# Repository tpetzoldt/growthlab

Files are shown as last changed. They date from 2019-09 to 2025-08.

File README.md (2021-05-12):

# growthlab

## Reale und virtuelle Wachstumsexperimente für Schule und Studium

## Real and virtual growth experiments for highschool and university students

Note to English speaking people: This repository is partly in German to support use by private persons and in schools in Germany.

Wachstums- und Verlustprozesse spielen in den ökologischen Wissenschaften eine entscheidende Rolle, nicht nur bei Symbolarten wie dem amerikanischen Bison [1], sondern auch bei Bakterien, beim Phytoplankton oder bei Fischen. Biologische Systeme besitzen eine vielfältige Dynamik und sind häufig komplex und rückgekoppelt, Simulationen und Experimente tragen zum Verständnis bei.

Das Repository ist eine lose Sammlung von Codes und Beschreibungen realer und virtueller Experimente zum Thema Wachstum für Schule und Studium. Beispiele sind web-basierte Simulationen (Laborversuch, Kläranlage, Flachsee) auf dem Computer oder Tablet, zum anderen um kleine Laborexperimente, die die reale mit der virtuellen Welt verbinden. Ziel ist Anschaulichkeit und ein einfacher Einstieg, die Luft nach oben ist offen.

Mit Hilfe von Flaschenversuchen wird das Populationswachstum einer Mikroalgenkultur beobachtet, z.B. von Scenedesmus. Die Messeinrichtung besteht aus kostengünstigen Bauteilen und eignet sich für Praktikumsversuche, Schulexperimente und Hobbyforscher. Das Grundprinzip ist ein Gestell mit roter Laserdiode, einem Fotowiderstand und einem Temperatursensor sowie einer LED-Beleuchtung und einem selbstgebauten Magnetrührer. Für die Stromversorgung genügt ein 5V-USB-Netzteil, z.B. von einem Handy. Die Messung kann direkt in der Flasche erfolgen, ohne den Versuch zu unterbrechen.

Die optische Dichte der Planktonkultur wird im einfachsten Fall manuell mit einem Voltmeter gemessen. In der vollen Ausbaustufe erfolgt die Messung mit einem WLAN-fähigen Mikrocontroller (Espressif ESP32), der gleichzeitig Beleuchtung und Rührer steuert, die Temperatur überwacht und die Daten an einen Server (z.B. einen Raspberry Pi "Bastelcomputer") oder einen Cloudservice überträgt.

Je nach Ausbaustufe ist das Experiment sehr einfach und erfordert weder Programmierung noch den Umgang mit einem Lötkolben. Im größeren Maßstab kann es ein fächerübergreifendes „Maker-Projekt“ (siehe [1,2]) für Teams werden: mechanischer Aufbau der Versuchsanordnung, Aufbau einer Schaltung, Mikrocontroller-Programmierung, Datenübertragung („Internet of Things“), Finden und Kennenlernen geeigneter Organismen, mikroskopische oder fotometrische Kalibrierung, Herstellen von Kulturmedien, Datenbankstruktur, statistische Datenanalyse und mechanistische Modellierung.

Der Versuchsaufbau wurde im Rahmen von Schülerpraktika (Gymnasium 11. und 12. Klasse) entwickelt. Die gewonnen Daten werden in Kursen zu ökologischer Statistik und Modellierung verwendet.

Ausführliche Dokumentation auf https://tpetzoldt.github.io/growthlab

### Grundideen

* [Ein Arduino steuert das Licht](https://tpetzoldt.github.io/growthlab/doc/blink.html)
* [Versuchsaufbau: Steuerung, Sensoren, Daten](https://tpetzoldt.github.io/growthlab/doc/versuchsaufbau.html)

### Schülerprojekte

* [Jugend Forscht-Projekt 2019/2020 -- Wachstumsversuche:](https://tpetzoldt.github.io/growthlab/doc/petzoldt_belger_2019.pdf) Experimente zur Messung des Wachstums einer Phytoplanktonpopulation
* [Jugend Forscht-Projekt 2020/2021 -- Algenlogger:](https://tpetzoldt.github.io/growthlab/doc/algenlogger.html) Versuchsoptimierung, Kalibrierung und Langzeitexperimente

### Quelltexte, Software und Bilder

* [Software-Repository](https://github.com/tpetzoldt/growthlab/)

### Literatur

[1] Snider, S. B. & Brimlow, J. N. (2013) An Introduction to Population Growth. Nature Education Knowledge 4(4):3 https://www.nature.com/scitable/knowledge/library/an-introduction-to-population-growth-84225544/ abgerufen am 2020-02-12

[2] Obama, B. (2014) Nation of Makers. https://obamawhitehouse.archives.gov/nation-of-makers abgerufen am 2019-05-28

[3] Wikipedia (2019) Makerbewegung. https://de.wikipedia.org/wiki/Maker abgerufen am 2019-05-28

### Nutzungsbedingungen

Falls nicht anders angegeben sind **Codes**, Texte und Abbildungen unter der GNU General Public License lizenziert, und zwar wahlweise unter der [GPL 2.0](http://www.gnu.org/licenses/gpl-2.0) oder der [GPL 3.0](http://www.gnu.org/licenses/gpl-3.0).

Die **Texte** und **Abbildungen** können außerdem (und falls nicht anders angegeben) auch gemäß der Creative Commons-Lizenz [CC BY 4.0](https://creativecommons.org/licenses/by/4.0/) verwendet werden. Falls im Einzelfall eine andere Lizenz gelten sollte, ist dies im jeweiligen Unterverzeichnis bzw. direkt im Dokument vermerkt.

Die Doppellizenzierung (GPL bzw. CC BY) berücksichtigt unterschiedliche Gepflogenheiten bei freier Software (Code) und freier Dokumentation (Texte, Abbildungen). In beiden Fällen, können Materialien im Rahmen von schulischen, akademischen oder privaten Projekten frei verwendet werden. Eine kommerzielle Nutzung ist ebenfalls möglich.

Namensnennung: Beide Lizenzen (GPL und CC BY) erfordern eine Namensnennung. Bitte nennen Sie die Institution und die im Dokument genannten Autor:innen und verlinken Sie mit der Webseite. Bei Rückfragen kontaktieren Sie bitte den [Maintainer](https://github.com/tpetzoldt).

Beispiel: Name der Autor:in (2019) Titel des Teildokuments. **growthlab**: Reale und virtuelle Wachstumsexperimente für Schule und Studium. TU Dresden, Institut für Hydrobiologie, https://github.com/tpetzoldt/growthlab 

----

<a href="https://open-educational-resources.de/">
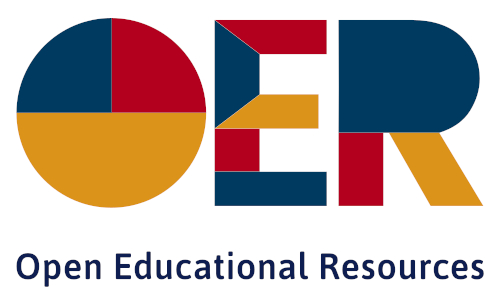
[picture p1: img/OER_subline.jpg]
OER Logo

</a>
<a href="https://creativecommons.org/licenses/by/4.0/">
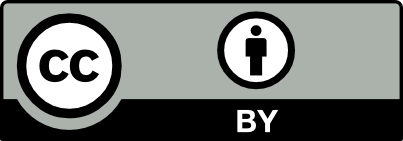
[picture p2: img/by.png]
CC BY Logo

</a>
<a href="http://www.gnu.org/licenses/gpl-3.0">
GPL v3 Logo
</a>

[tpetzoldt](https://github.com/tpetzoldt) 2021-05-12

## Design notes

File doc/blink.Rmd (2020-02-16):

---
title: "Blinkender LED-Streifen"
author: "Thomas Petzoldt"
date: "2019-10-07"
output: 
  html_document:
    numbersections: true
    toc: true
    toc_float:
      collapsed: false
      smooth_scroll: true
    code_folding: hide

---

# Grundidee

Die Grundidee besteht darin, einen LED-Streifen zur Beleuchtung eines 
Wachstumsversuchs zu verwenden. Mit Hilfe eines Microcontrollers sollen unterschiedliche
Hell-Dunkel-Zyklen einstellbar sein, z.B. 12:12, 16:8 oder 2:2 Stunden.

Das Experiment ist als Schüler-, Studien- und Praktikumsexperiment vorgesehen. 
Bei entsprechend höherem Aufwand und Kosten für Mechanik, Optik und Elektronik 
ist eine Weiterentwicklung für Forschungszwecke denkbar, allerdings sind
solche Geräte bereits kommerziell erhältlich.

Im folgenden soll der Versuch, ausgehend von der Grundidee, schrittweise bis zur
Vollautomatisierung und zur Integration in ein Netzwerk (IoT -- Internet of Things)
vorgestellt werden.

Das hier vorgefundene Dokument stellt den jeweiligen Arbeitsstand dar.

# LED-Streifen

LED-Streifen sind in zahlreichen unterschiedlichen Versionen erhältlich, die sich durch Leistung, Lichtfarbe, und Versorgungsspannung unterscheiden. Die benötigte Leistung ist im Regelfall höher, als die vom Arduino oder ESP am digitalen Pin erreichbaren Werte, außerdem beträgt die Versorgungsspannung oft 12 oder 24V und nicht 3.3 oder 5V wie beim Mikrocontroller. Es sind deshalb Bauteile zur Steuerung etwas höherer Leistungen erforderlich.

Die folgende Anleitung beginnt zunächst mit der Steuerung von einfachen LEDs, anschließend wird das Experiment zur Steuerung etwas höherer Leistungen erweitert.

# Experiment 1 

Die einfachste Aufbaustufe zeigt bereits das Grundprinzip.

Als elektronische Bauelemente genügen neben der LED und dem Arduino ein sogenanntes *Breadboard* (Steckbrett),
1 Widerstand, 1 LED und ein paar Steckbrücken oder Basteldraht (0.5mm Durchmesser). Wichtig ist, dass
die LED immer mit einem Vorwiderstand betrieben werden muss, sonst geht sie kaputt.

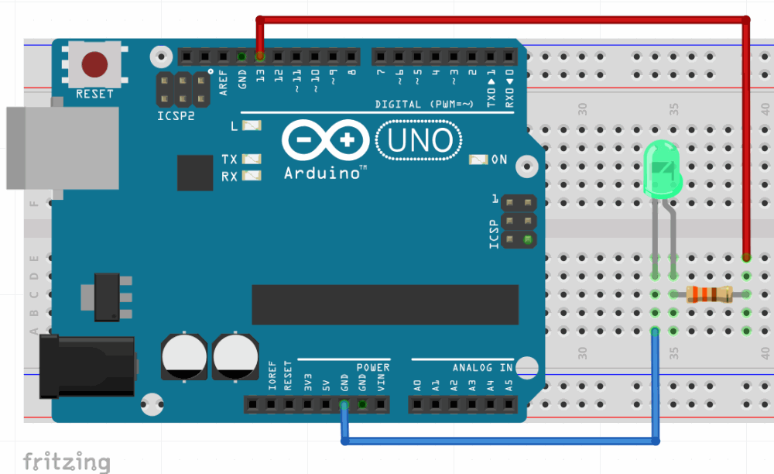
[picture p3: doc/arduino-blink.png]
Schaltungsaufbau


Eine detaillierte Einführung in die Mikrocontrollerprogrammierung würde den Rahmen dieses Projekts
sprengen. Die Installation Arduino-IDE sowie erste Gehversuche sind auf diversen Internetseiten sehr ausführlich beschrieben, z.B. auf https://www.arduino.cc/en/Guide/HomePage

### Einfaches Blink-Beispiel

Das Blink-Beispiel bringt zunächst die interne LED des Arduino zum blinken, 
anschließend soll eine externe LED an PIN 13 angesteuert werden. Der kürzere Pin der LED wird mit dem Minuspol (Masse) verbunden. Der längere Pin (Pluspol) wird über den Vorwiderstand (hier 300 Ohm) an Pin 13 des Arduino angeschlossen.

```{c eval=FALSE}
/*
  Control LED on an "Arduino Uno" compatible board
  Set IDE to Arduino/Genuino Uno
  License: public domain
*/

// The Arduino Uno internal LED is connected to pin 13    
#define LED_1 13

void setup() {
  pinMode(LED_1, OUTPUT);
}

// the loop function runs over and over again forever
void loop() {
  digitalWrite(LED_1, HIGH);
  delay(2000);
  digitalWrite(LED_1, LOW);
  delay(2000);
}
```

### Blink ohne Delay

Das folgende Beispiel verzichtet auf die "delay"-Funktion und verwendet stattdessen 
den Millisekunden-Zähler der internen Quarzuhr des Arduino. Das ist genauer, außerdem
wird der Programmfluss nicht durch "delay" unterbrochen. 
Somit lassen sich parallel Messaufgaben durchführen oder weitere LEDs mit unterschiedlichem 
Blinkintervall steuern.

```{c eval=FALSE}
/*
  Control LED on an "Arduino Uno" compatible board
  Set IDE to Arduino/Genuino Uno

  Code modified from:
  http://www.arduino.cc/en/Tutorial/BlinkWithoutDelay
  
  License: public domain
*/

// constants won't change. Used here to set a pin number:
const int ledPin =  13;// the number of the LED pin

// Variables will change:
int ledState = LOW;             // ledState used to set the LED

// Generally, you should use "unsigned long" for variables that hold time
// The value will quickly become too large for an int to store
unsigned long previousMillis = 0;        // will store last time LED was updated

// constants won't change:
const long interval = 1000;           // interval at which to blink (milliseconds)

void setup() {
  // set the digital pin as output:
  pinMode(ledPin, OUTPUT);
}

void loop() {
  // here is where you'd put code that needs to be running all the time.

  // check to see if it's time to blink the LED; that is, if the difference
  // between the current time and last time you blinked the LED is bigger than
  // the interval at which you want to blink the LED.
  unsigned long currentMillis = millis();

  if (currentMillis - previousMillis >= interval) {
    // save the last time you blinked the LED
    previousMillis = currentMillis;

    // if the LED is off turn it on and vice-versa:
    if (ledState == LOW) {
      ledState = HIGH;
    } else {
      ledState = LOW;
    }

    // set the LED with the ledState of the variable:
    digitalWrite(ledPin, ledState);
  }
}
```

## Aufgabe: Steuerung von 2 LEDs

Baue eine Schaltung auf, die 2 LEDs mit unterschiedlichem Blinkrhythmus steuert, z.B. 16:8 Sekunden
und 2:2 Sekunden. Arbeitsschritte:

* Aufbau der Schaltung
* Erweiterung des Code-Beispiels
* Ausprobieren
* Dokumentation von Schaltung und Code.

Zum Zeichnen des Codes kann entweder ein normales Grafikprogramm verwendet werden oder
das Programm Fritzing (https://fritzing.org). Die App wird zwar leider nicht mehr weiterentwickelt, leistet aber nach wie vor gute Dienste.

# Experiment 2

### Arduino steuert LED-Streifen

Für das folgende Experiment benötigen wir ein kurzes Stück eines LED-Streifens (24 V), 
ein DC-DC-Wandlermodul (Step-up Modul MT 3608) und einen Mosfet-Transistor (z.B- IRLZ 24N).

Das DC-DC-Wandlermodul konvertiert die Spannung des Arduino (5V) in die vom 
LED-Streifen benötigten 24V (bzw. 12 V, je nach Typ). Hierzu verbinden wir 
In- und In+ des Moduls mit Masse und 5V-Leitung des Arduino (blaue bzw. rote Leitung).

Mit Hilfe der kleinen Schraube des Einstellreglers und einem Voltmeter stellen 
wir die benötigte Ausgangsspannung ein. Achtung, bei einem neuen Modul muss man 
meistens zunächst 20 Umdrehungen gegen den Uhrzeigersinn drehen, bis etwas passiert.

Der Mosfet-Transistor funktioniert als elektronischer Schalter, d.h. die 5V des 
Arduino (weiße Leitung) schalten die höhere Spannung für den LED-Streifen.
Im vorliegenden Beispiel sind die 24V direkt mit dem LED-Streifen verbunden und 
der Transistor schaltet die Masseleitung (blau bzw. grün). Alternativ kann man 
auch die Spannungsleitung schalten.

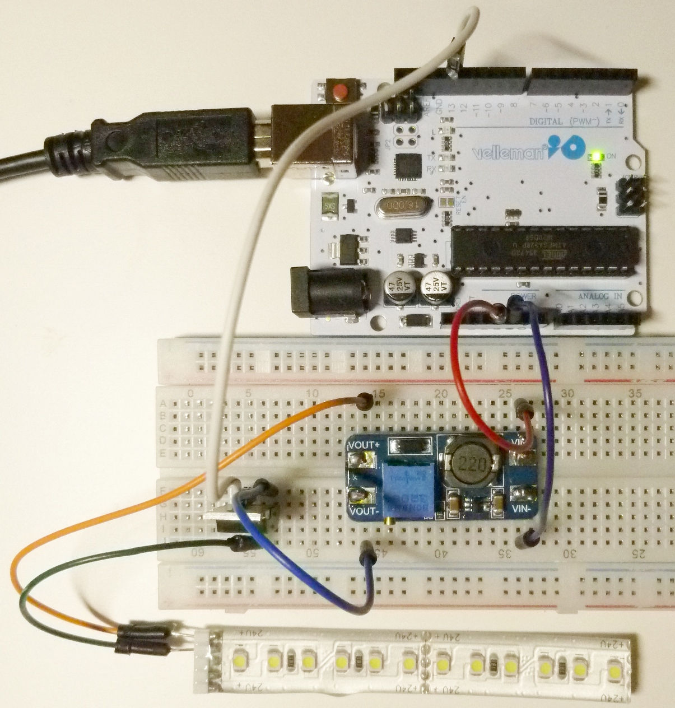
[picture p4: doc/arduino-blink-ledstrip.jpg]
Arduino steuert LED-Streifen


### Wichtige Hinweise:

* Beim Arbeiten mit verschiedenen Spannungen muss genau darauf geachtet werden, 
dass weder der Arduino noch die LED-Streifen und auf keinen Fall der PC eine 
Überspannung erhalten, ansonsten können die Bauteile "durchbrennen".
* **Solange die Schaltung mit dem PC verbunden ist: rote Leitung herausziehen!**
Zum Schutz des Computers sollte man den Step-Up-Regler unbedingt abtrennen, 
solange das USB-Kabel mit dem PC verbunden ist. 
* Den Arduino versorgt man nach Abtrennung der USB-Verbindung über die runde Buchse 
mit einem 9V-Netzteil.
* Bei der Verwendung von LED-Streifen muss die Gesamtlast berücksichtigt werden: 
Netzteil, Arduino-Spannungsregler und MT 3608 besitzen eine begrenzte Leistungsfähigkeit. 
Die maximale Ausgangsstromstärke des MT 3608 beträgt 2A, die maximale Stromstärke 
von USB 2.0 nur 500 mA bei 5V.
* Bei größeren LED-Streifen sollte man die Spannung besser dem Vin-Pin 
entnehmen (direkt vom Netzteil statt über den 5V-Regler des Arduino) oder ein 
separates Netzteil verwenden, siehe z.B. https://forum.arduino.cc/index.php?topic=380336.15 

----

**Copyright and original author:** [tpetzoldt](https://github.com/tpetzoldt), `r Sys.Date()`

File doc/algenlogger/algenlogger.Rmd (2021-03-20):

---
title: 'Algen-Wachstumslogger'
author: "Saramaria Schreib und Thomas Petzoldt"
date: "January 2021"
output:
  html_document: default
---

```{r setup, include=FALSE}
knitr::opts_chunk$set(echo = TRUE)
```

## Grundidee

Sachverhalte werden schneller verstanden und langfristig abgespeichert, wenn das Wissen praktisch angewendet wurde. Genau das ist das Ziel, das mit diesem Projekt erreicht werden sollte.

Beschrieben wird eine Apparatur, in der Wachstumsprozesse  einer Grünalgen-Batch-Kultur aufgezeichnet und anschließend visualisiert ausgewertet werden können. Verwendet wurde zur Konstruktion einfache Messeinrichtung ein unkomplizierter Aufbau sowie eine leicht zu verstehende und den Wunschvorstellungen entsprechend anpassbare Software.

Die Apparatur wurde für die Verwendung in schulischen und universitären Praktika entwickelt. Die Aufzeichnung von Wachstumskurven ist ohne großen Aufwand möglich. Zudem wird die Bedeutung von Kalibrierungen deutlich. Der Umgang mit Mikrocontrollern kann erlernt werden.

# Der Algen-Wachstumslogger

Versuchsapparaturen LED-Streifen ein
In diesem Experiment wurden drei baugleiche Apparaturen konstruiert. Diese sind in der obenstehenden Abbildung gezeigt. Durch die Plastik-Kisten sind sie voneinander abgeschirmt und können mit unterschiedlichen Lichtrhythmen betrieben werden ohne sich gegenseitig zu beeinflussen.
Verwendet wurden leicht erwerbbare Materialen, wie beispielsweise eine Grundplatte aus Sperrholz, Gewindestäbe und Muttern sowie Polystyrol als Standplatte für die Laborflasche mit der Algenprobe.

## Technik
Als technische Bauteile wurden handlesübliche sowie preisgünstige Geräte verwendet. Auf dem Steckbrett unten zeigt die Anordnung. Die Step-Down-Module transferieren die Netzteilspannung in die jeweils benötigte Spannung. Somit wurde den LED-Streifen mit dem rechten Modul eine Spannung von ca. 18V bereitgestellt. Die restlichen Bauteile wurden mit  7,75V betrieben.

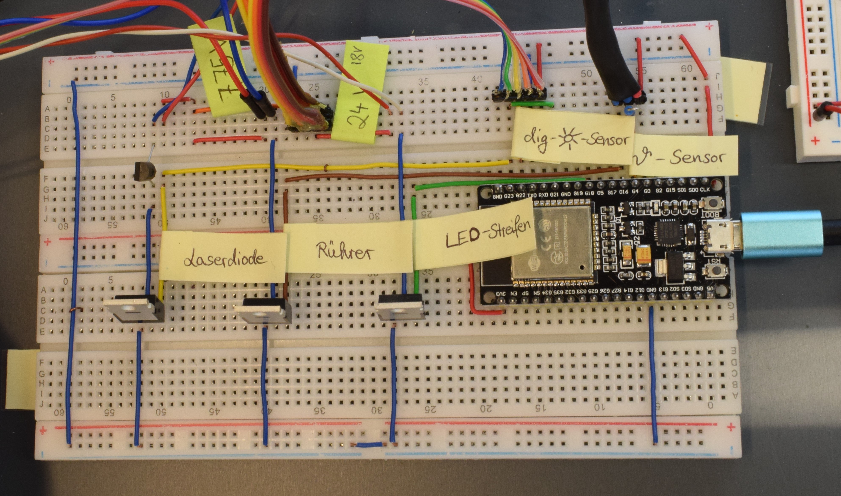
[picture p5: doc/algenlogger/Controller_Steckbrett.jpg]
über Mikrocontroller gesteuerte Bauteile

Tabelle mit genauer Bezeichnung und Grund der Verwendung einfügen

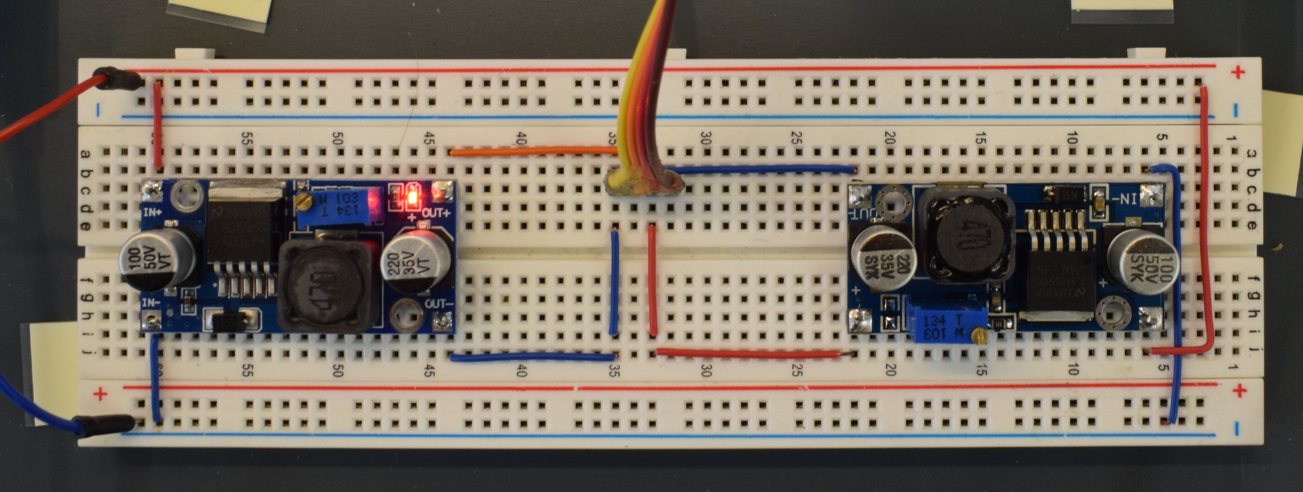
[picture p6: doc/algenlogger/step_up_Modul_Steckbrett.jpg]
Steckbrett der Step-Down-Module


## Schaltplan

Die Steckbrettanordnung wurde mit dem Programm [**fritzing**](https://fritzing.org/) digitalisiert, das ebenfalls auf [Github](https://github.com/fritzing/fritzing-app) frei verfügbar ist. 

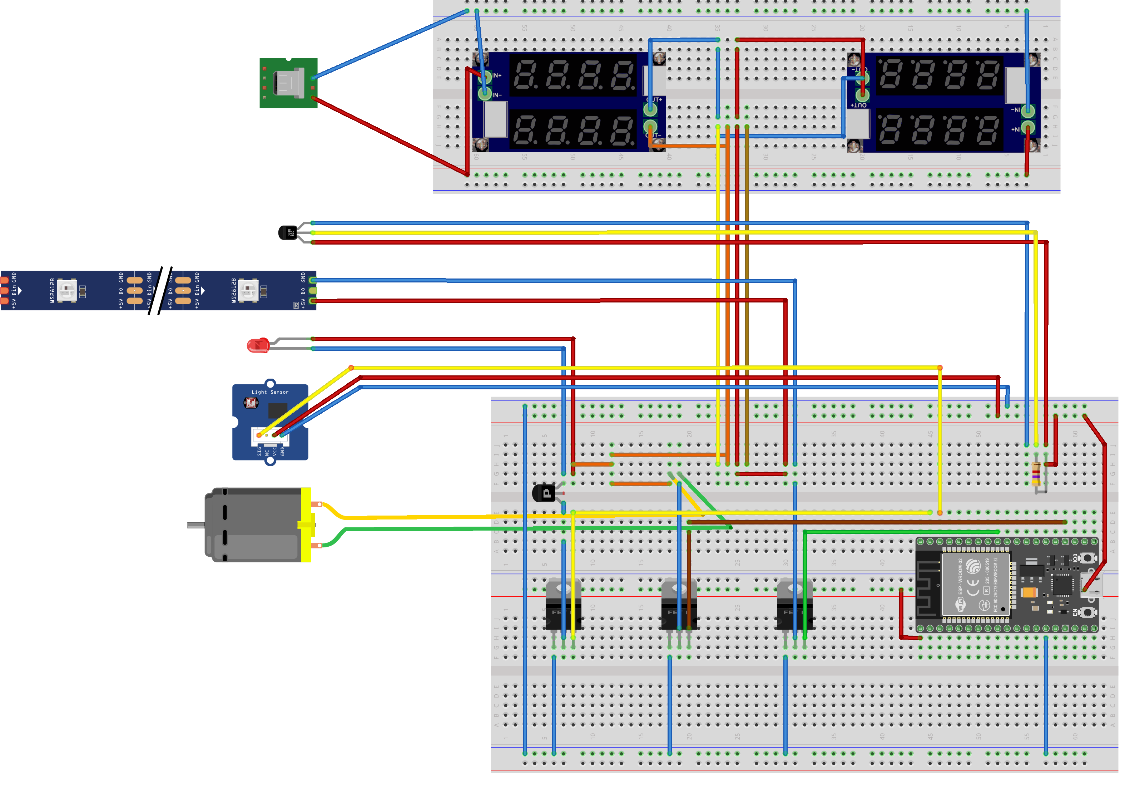
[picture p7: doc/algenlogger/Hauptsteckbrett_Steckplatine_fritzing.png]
Steckbrettanordnung, erstellt mit **fritzing**. Der [**fritzing**-Entwurf](https://github.com/tpetzoldt/growthlab/blob/master/circuits/algenlogger_hauptsteckbrett.fzz) kann für eigene Erweiterungen angepasst werden.
 

## Software

Mit dem hier verlinkten R-Skript werden die Messungen in den Apparaturen gesteuert. Die LED-Streifen werden an- bzw. ausgeschaltet, die Temperatur wird aufgezeichnet, die Laserdiode wird im Messintervall eingeschaltet und zeitgleich werden die Informationen des digitalen Lichtsensors ausgewertet und die Messdaten zwischengespeichert.

hier R-Skript reinstellen

Anschließend werden die Daten derzeit an den zentralen Server der TU-Dresden übermittelt. Von dort aus kann auch aus externen Internetanbindungen, wie das häusliche W-LAN, auf den derzeitigen Stand der Messungen zugegriffen werden. In growthlab kann man den Zeitraum des zu betrachtenden Messintervalls einstellen. Es werden automatisch Diagramme erstellt, die die Temperaturmesswerte sowie die Messwerte des digitalen Lichtsensors in Abhängigkeit von der Zeit darstellen.

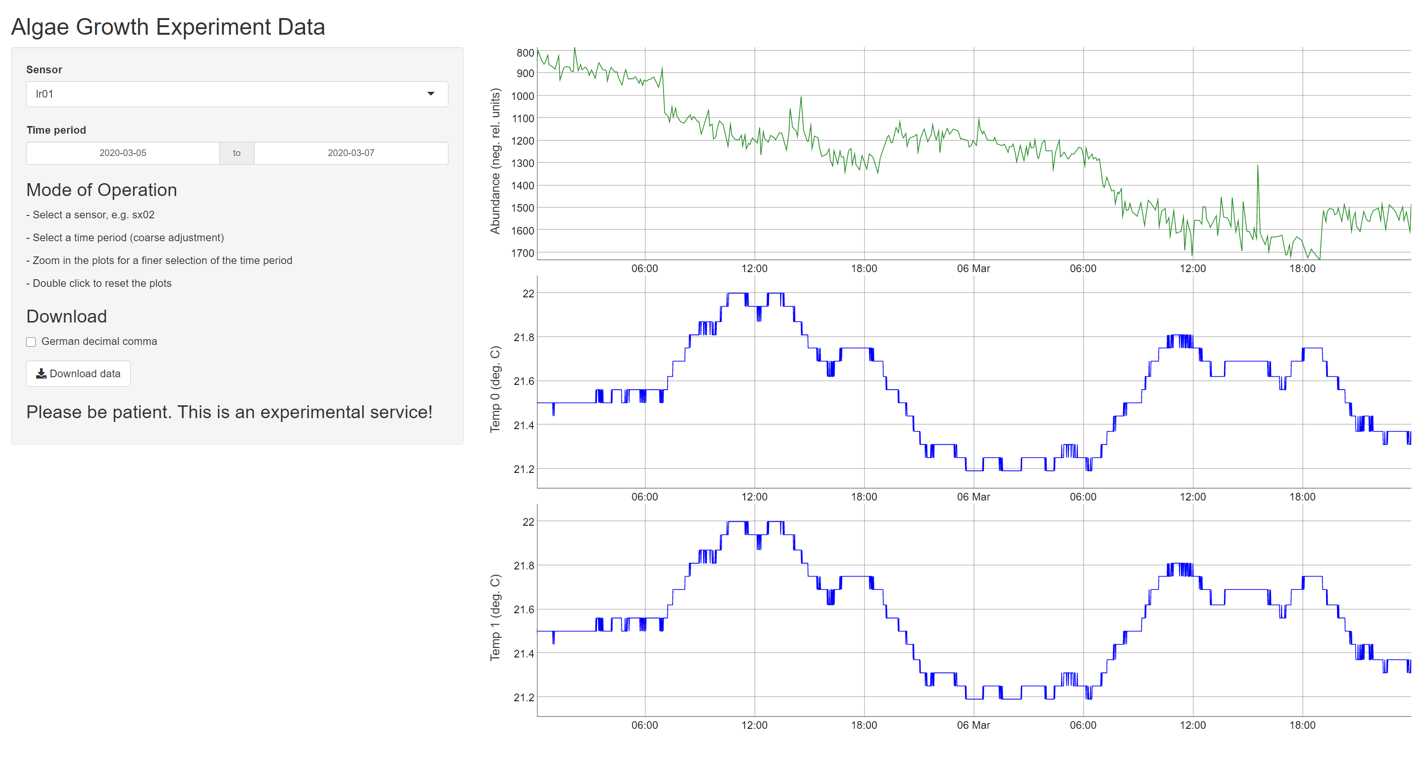
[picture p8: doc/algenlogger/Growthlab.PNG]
Messdaten Growthlab im Zeitraum vom 05. bis 07.März 2020


# Auswertung der Daten

## Kalibrierung

Formel zur Umrechnung der Messwerte in auswertbare relative Algenkonzentration
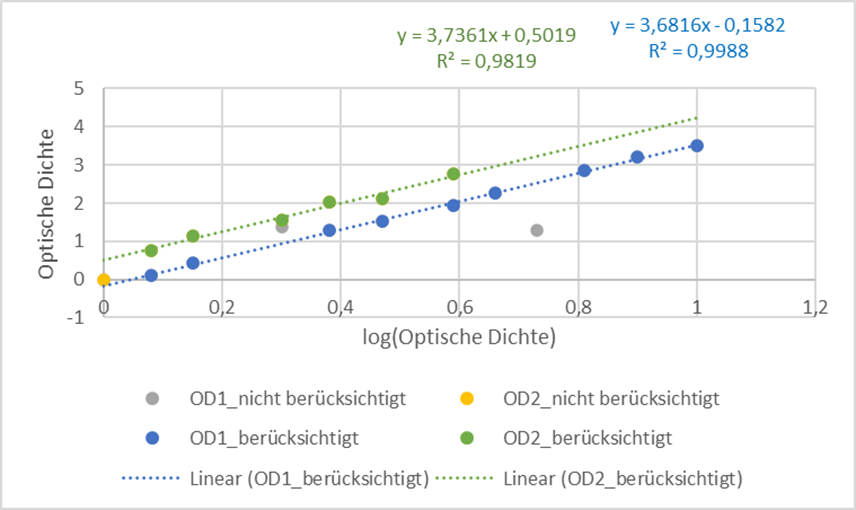
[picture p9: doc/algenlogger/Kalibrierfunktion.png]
lineare Kalibrierfunktion


## Wachstumskurven

Die Wachstumskurven, die aus den bisher aufgezeichneten Daten erstellt werden konnten, zeigen einen typischen logistischen Verlauf. Auf eine anfängliche lag-Phase folgt die Phase des exponentiellen Wachstums. Nach etwa zwei Wochen ist die Maximalkonzentration erreicht. Das nachfolgende Diagramm zeigt lediglich die Meswerte, die um 18 Uhr aufgezeichnet wurden. Kleine Unregelmäßigkeiten sind auf geringe Messfehler der Messeinrichtung zurückzuführen.

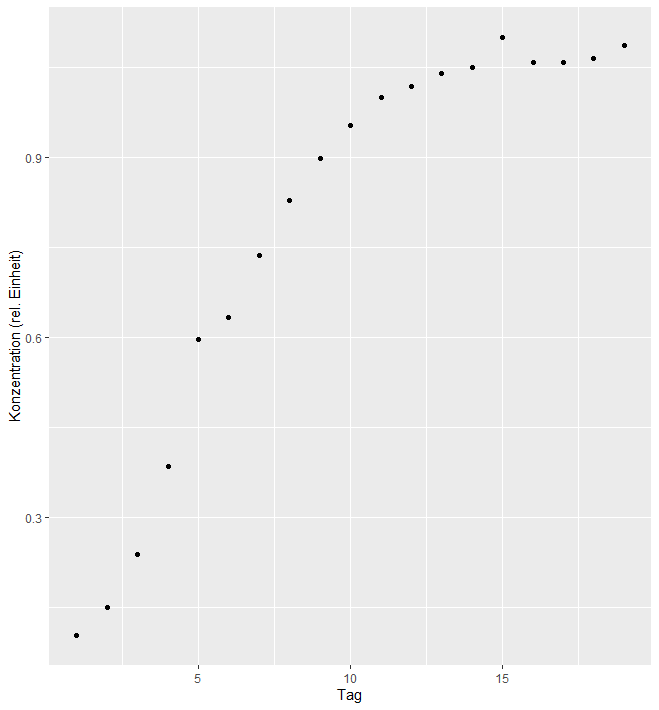
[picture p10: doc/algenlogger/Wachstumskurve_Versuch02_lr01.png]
Wachstumskurve 11.03.-30.03.2020 (Licht ein: 8 Uhr, Licht aus: 20 Uhr)


Die Datenauswertung in RStudio bietet vielfältige Möglichkeiten, die Messwerte in Diagramme zu überführen. So können auch zu zwei unterschiedlichen Tageszeiten (beispielsweise früh und abends) die Messdaten ausgelesen werden. Im untenstehenden Diagramm sind die Messwerte um 6 Uhr grün sowie die Messwerte um 18 Uhr rot dargestellt. Somit lassen sich Anpassungen des Photosystems an Licht- / Dunkelverhältnisse veranschaulichen und erklären.

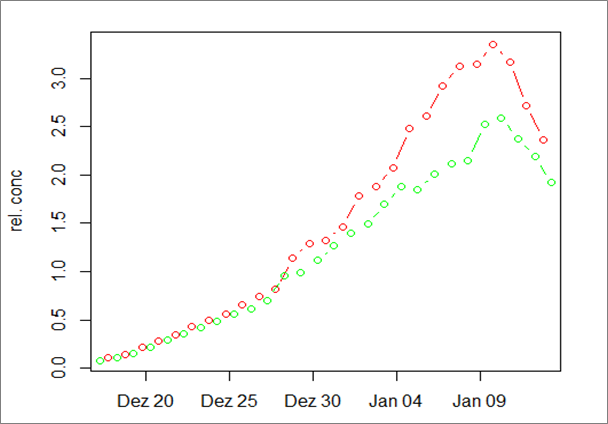
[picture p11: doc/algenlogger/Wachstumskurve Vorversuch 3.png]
Wachstumskurve (Licht ein: 6 Uhr, Licht aus: 22 Uhr)


Aus dieser Wachstumskurve wird ersichtlich, dass die Probe nach etwa drei Wochen fällt die relative Konzentration der Algen wieder ab. Die Algenprobe ist in diesem Fall verklumpt, die maximale Konzetration wurde erreicht und es kam zum Algensterben.

## Weitere Möglichkeiten der Datenanalytik

Auch weiterführende Begriffe, wie Wachstumsrate und Verdopplungzeit lassen sich mit den aufgenommenen Daten graphisch darstellen. 
Das untenstehende Diagramm zeigt beispielhaft die Wachstumsrate. Auch hier lassen sich die Beobachtungen des zweiten Wachstumsdiagramms bestätigen. Mit zunehmender Zeit sinkt die Wachstumsrate; die Algen wachsen somit zunehmend langsamer. Schließlich fällt die Wachstumsrate unter Null, die Probe ist gekippt. 

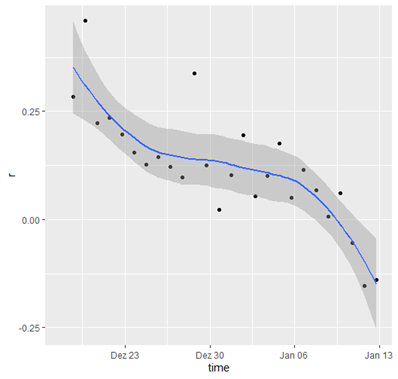
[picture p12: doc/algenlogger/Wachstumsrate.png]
Wachstumsrate


## Literatur und Internetquellen

Morgenstern, K. (2019) Fritzing, Electronics made easy. https://fritzing.org/ abgerufen am 2021-01-23

[Fritzing-Entwurf der Steckbrettanordnung](https://github.com/tpetzoldt/growthlab/blob/master/circuits/algenlogger_hauptsteckbrett.fzz)

<hr></hr>

Diese Anleitung entstand im Rahmen von [Jugend Forscht](
Home - Stiftung Jugend forscht e. V.
www.jugend-forscht.de) (2021): Saramaria Schreib
(Autorin), Thomas Petzoldt (Betreuer, Maintainer). Das Dokument, Fotos, 
Skripte und Daten stehen unter der [CC BY 4.0](https://creativecommons.org/licenses/by/4.0/)- Lizenz.

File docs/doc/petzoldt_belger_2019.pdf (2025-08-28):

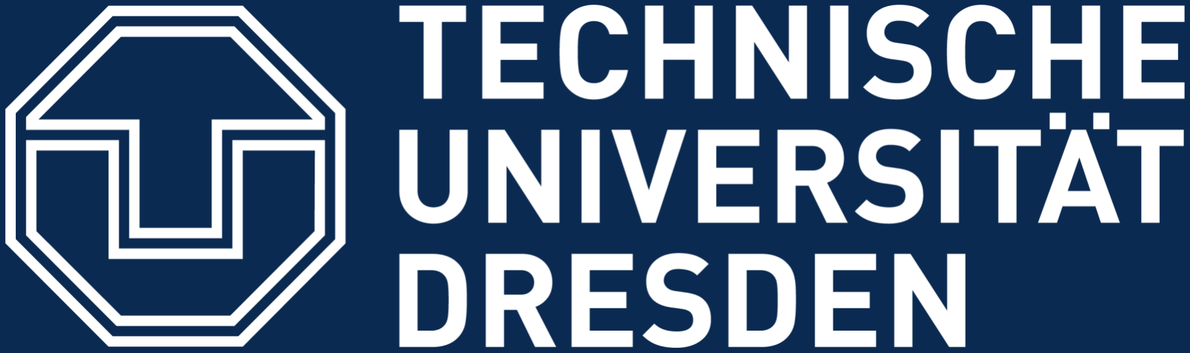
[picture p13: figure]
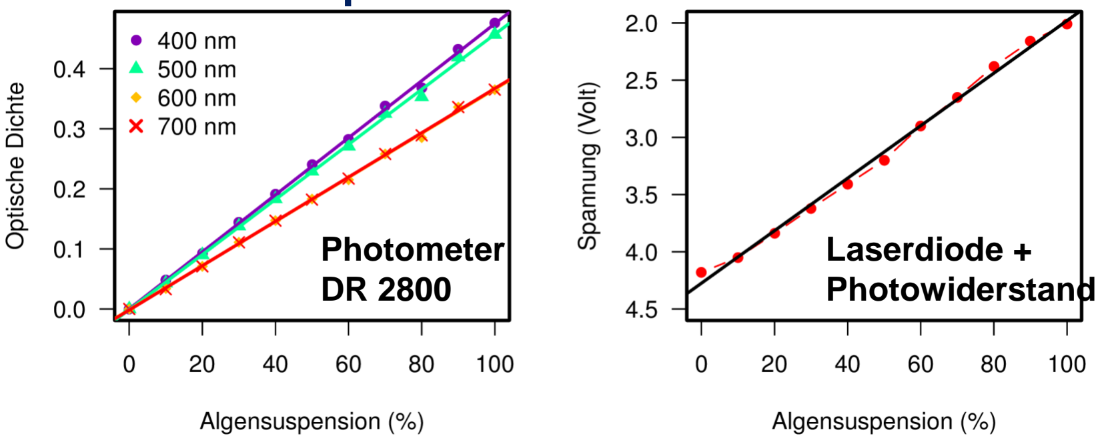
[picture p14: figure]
Photometer DR 2800; Laserdiode + Photowiderstand

Mitglied im Netzwerk von:

# Zielstellung

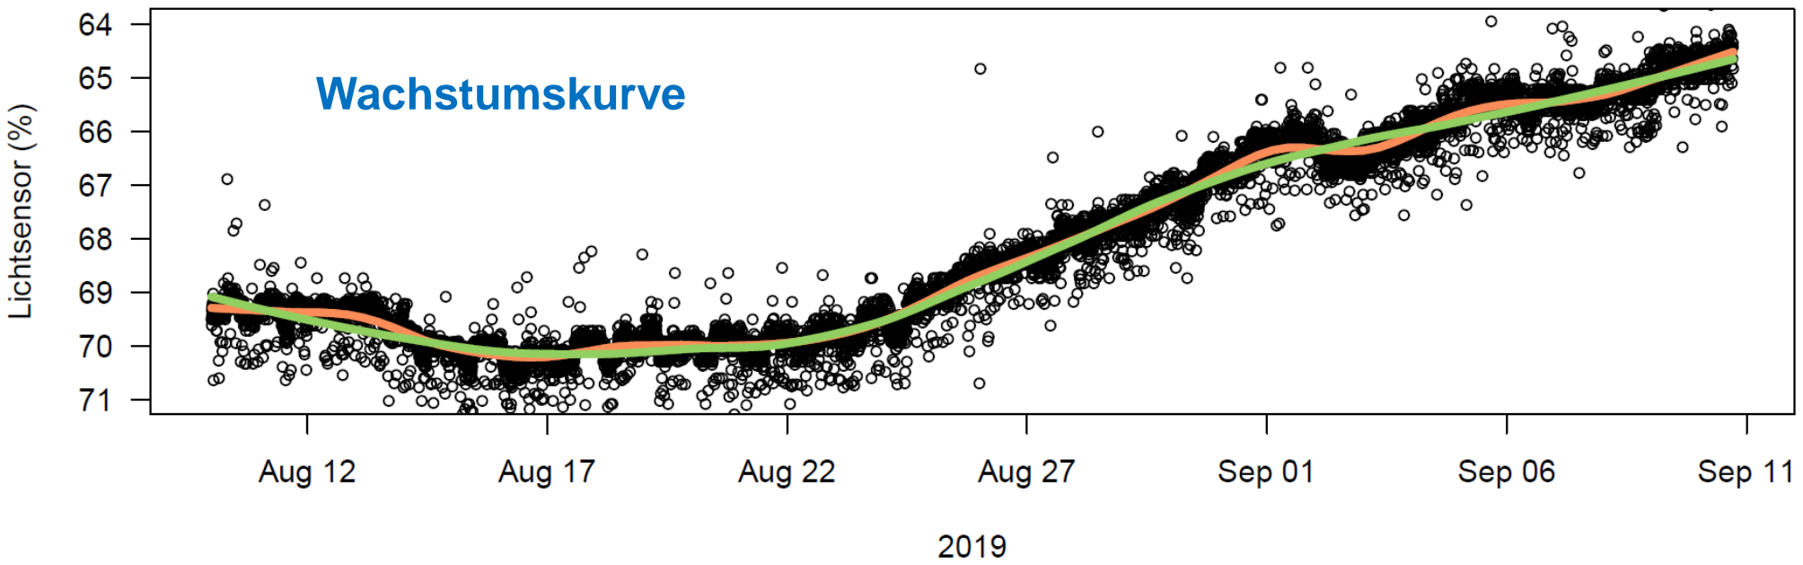
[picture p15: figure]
Wachstumskurve

Wachstums- und Verlustprozesse spielen in den ökologischen Wissenschaften eine entscheidende Rolle. Ziel ist ein möglichst einfacher und kostengünstiger Versuchsaufbau für Schule und Studium, um Wachstumsprozesse zeitlich dicht zu beobachten.

# Experiment 1: Analoge Messung

Im einfachsten Fall besteht die Messanordnung lediglich aus einer Laserdiode, einem Photowiderstand und einem Voltmeter in einer Spannungsteilerschaltung.

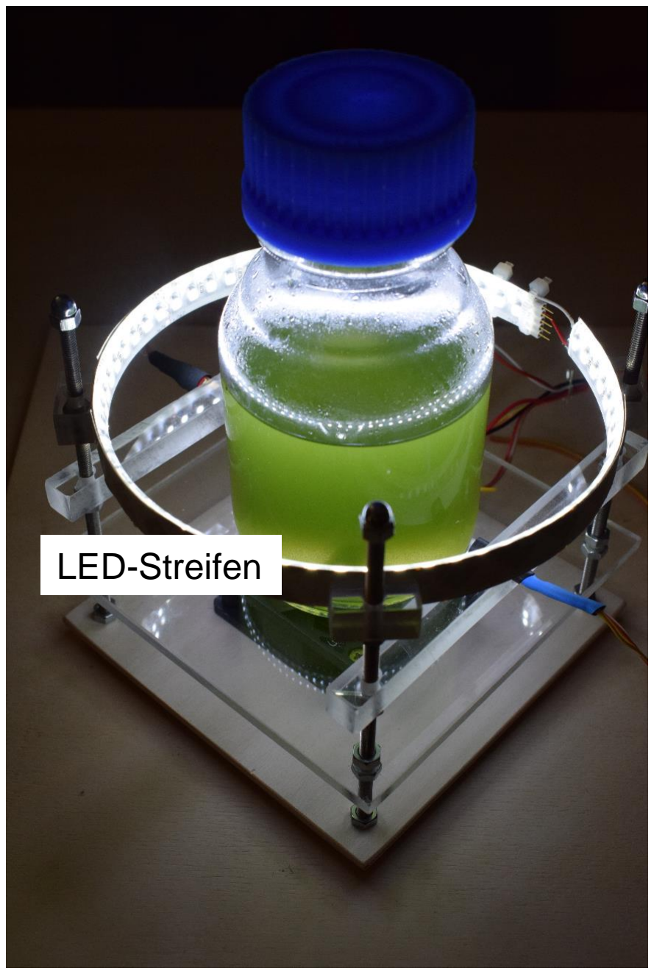
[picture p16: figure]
LED-Streifen

# Experiment 2: Digitalisierung

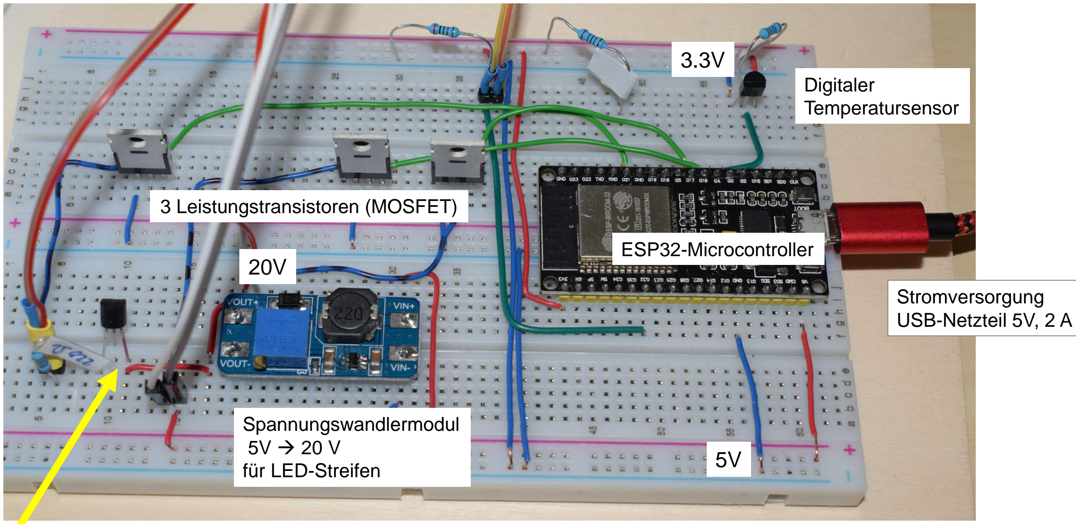
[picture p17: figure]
Spannungswandlermodul 5V → 20 V für LED-Streifen; ESP32-Microcontroller; 3 Leistungstransistoren (MOSFET); Digitaler Temperatursensor; Stromversorgung USB-Netzteil 5V, 2 A

Anstelle des Voltmeters wird ein Mikrocontroller eingesetzt. Dieser fungiert als Bindeglied zwischen der realen und der virtuellen Welt:
- Digitalisierung von Messsignalen
- Steuerung, z.B. von LEDs oder Motoren
- Ausgabe von Messsignalen über USB oder Display

Messanordnung mit einem „Arduino“, der weit verbreiteten Urform des Bastel-Mikrocontrollers. Statt eines Photowiderstands wird hier ein digitaler Lichtsensor verwendet. Dieser ist genauer und temperatur-kompensiert. Zur Anzeige dient ein OLED-Display.

# Experiment 3: Internet of Things (IoT)

In der vollen Ausbaustufe (Abb. oben) wird ein ESP32-Microcontroller verwendet. Dieser steuert die Messung und überträgt die Messungen von optischer Dichte und Temperatur per WLAN an einen Datenbankserver.

Der Microcontroller steuert die Beleuchtung, die Laserdiode und den periodischen Rührer, so dass die Messung nicht durch Beleuchtung oder Rührer gestört wird. Da Laserdioden stark temperaturabhängig sind, wird ein Konstantstrom-Bauelement 20mA vorgeschaltet.

Die Zeit wird von einem Internet-Zeitserver bezogen. So lässt sich die Messung mit anderen Mess- und Steuergeräten, z.B. WLAN-Steckdosen für weitere Lichtquellen, Belüftung, Thermostat oder Pumpen sekundengenau synchronisieren.

Der Datenbankserver empfängt die Daten mit dem IoT-Standardprotokoll MQTT und speichert die Ergebnisse in eine MySQL-Datenbank. Ein stromsparender Raspberry Pi-Kleinstcomputer kann mehrere Versuche parallel verwalten.

# Grundidee

Messung der optischen Dichte direkt im Versuchsgefäß mittels Laserdiode und Lichtsensor
- Mikrocontroller steuert Messung, Beleuchtung und Rührer
- Speicherung der Messungen direkt in eine Datenbank
- Kostengünstig und leicht nachbaubar
- Stufenweiser Aufbau von simpel bis vollautomatisch

# Ergebnis

Der Versuchsaufbau wurde im Rahmen eines Schülerpraktikums (Gymnasium 11. Klasse) erfolgreich getestet. Die gewonnen Daten werden in Kursen zur Ökologischen Modellierung und Statistik verwendet.

Analoge Messanordnung ohne Mikrocontroller und ohne Programmierung

LED und Photowiderstand
in Spannungsteilerschaltung

Lichtsensor

Konstantstrombauteil
20mA für Laser-LED

WLAN-Router

Datenbank-Server

MQTT
SQL

Internet-Zeitserver

NTP

PC

Smartphone

Laser-LED

Magnetrührer

### https://tu-dresden.de/hydrobiologie

# https://tpetzoldt.github.io

# Didaktischer Wert

- Kennenlernen, wie Umweltfaktoren das Wachstum steuern
- Einfacher Einstieg ohne Programmierung oder Lötkolben
- Voll ausgebaut ein fächer-integrierendes „Maker-Projekt“ für Teams: mechanischer Aufbau, Elektronik, Programmierung, Kulturmedien, Analytik, Datenbanken, Statistik, Modellierung und organismische Biologie.

+

### Anwendungsbeispiel: Wachstumsversuch mit unterschiedlichen Nährmedien

- Nährmedien mit
unterschiedlicher C-Quelle
- Randomisierter
Versuchsansatz in einer
Klimakammer
- Optische Dichte der
Algensuspension während
des Versuchsablaufs
mehrmals gemessen.
- Die Flaschen bleiben
verschlossen, um Luft-CO2
Eintrag zu vermeiden.
- Datenanalyse und Statistik mit R: Visualisierung, Datenglättung, ANOVA

Schaltung, Programme, Anleitungen,

## Downloads, Daten, Modellierung

LED-Streifen
Lichtsensor

Laserdiode

Die Wellenlänge der Laserdiode (670nm) entspricht gut dem mit einem Laborphotometer (Hach-Lange DR 2800) abgeschätzten Absorptionsmaximum von 600 bis 700 nm (gelbe und rote Linien).

Die Kalibriergerade der
Messanordnung zeigt einen
annähernd linearen Verlauf. Weitere Vergleiche ermöglichen mikroskopische Zählung, POCoder Chlorophyll-Bestimmung.

### Kalibrierung mit Verdünnungsreihe: Optische Dichte in Profi- und Selbstbauphotometer

I

2C-Bus

OLED
Sensor

# Aufbau eines Experiments zur Messung des Wachstums einer Phytoplanktonpopulation

# Thomas Petzoldt¹ und Christoph Belger

2

### 1 TU Dresden, Institut für Hydrobiologie, 01062 Dresden, thomas.petzoldt@tu-dresden.de 2 Martin-Andersen-Nexö-Gymnasium Dresden, Haydnstraße 49, 01309 Dresden

### Kosten

Die verwendete Elektronik
(ESP32, LED-Streifen,
Sensoren, Rührer) ist
kostengünstig und
energieeffizient.

Für das links gezeigte Beispiel genügt ein Handy-Netzteil.

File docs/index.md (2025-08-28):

---
pagetitle: growthlab -- Reale und virtuelle Wachstumsexperimente für Schule und Studium
--- 

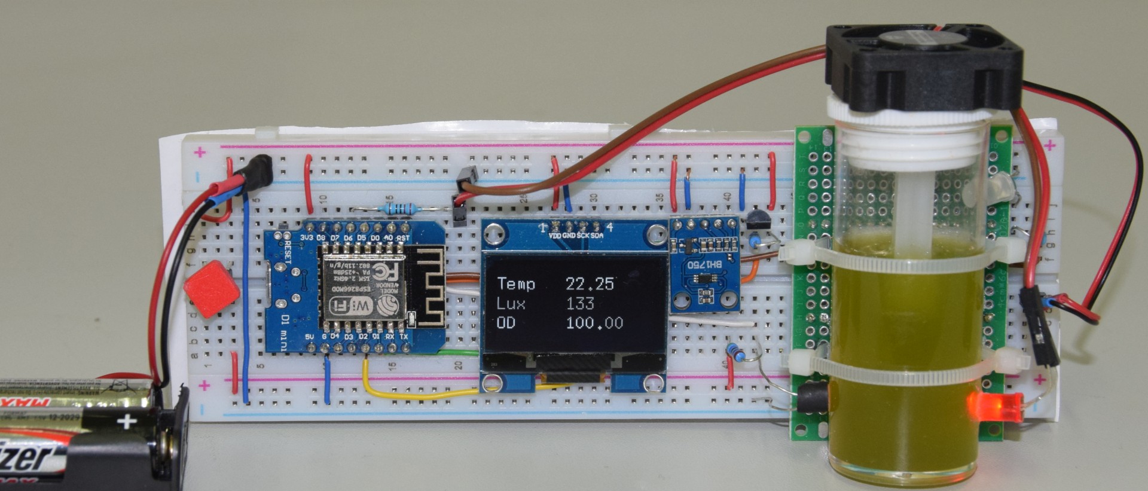
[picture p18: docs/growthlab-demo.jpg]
Demo-Aufbau mit Mikroprozessorsteuerung im Miniformat


## Reale und virtuelle Wachstumsexperimente für Schule und Studium

Das Projekt verfolgt das Ziel, Wachtumsprozesse von Organismen zu veranschaulichen. Hierfür werden verschiedene Versuche entwickelt und praktisch getestet, von der einfachen
Trübungsmessung bis hin zum vernetzten mikroprozessorgesteuerten Messsystem.
Zusätzlich zur Hard- und Software werden auch die gewonnenen Daten und Erfahrungen geteilt.

### Grundideen

* [Ein Arduino steuert das Licht](doc/blink.html)
* [Versuchsaufbau: Steuerung, Sensoren, Daten](doc/versuchsaufbau.html)

### Schülerprojekte

* [Jugend Forscht-Projekt 2019/2020 -- Wachstumsversuche:](doc/petzoldt_belger_2019.pdf) Experimente zur Messung des Wachstums einer Phytoplanktonpopulation
* [Jugend Forscht-Projekt 2020/2021 -- Algenlogger:](doc/algenlogger.html) Versuchsoptimierung, Kalibrierung und Langzeitexperimente

### Quelltexte, Software und Bilder

* [Software-Repository](https://github.com/tpetzoldt/growthlab/)

<hr>

Note to English speaking people: This repository is mainly in German to 
support educational use in Germany. Translations are welcome.

[Maintainer: tpetzoldt](https://github.com/tpetzoldt) 2021-01-14

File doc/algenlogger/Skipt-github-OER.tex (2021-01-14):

% Options for packages loaded elsewhere
\PassOptionsToPackage{unicode}{hyperref}
\PassOptionsToPackage{hyphens}{url}
%
\documentclass[
]{article}
\usepackage{lmodern}
\usepackage{amssymb,amsmath}
\usepackage{ifxetex,ifluatex}
\ifnum 0\ifxetex 1\fi\ifluatex 1\fi=0 % if pdftex
  \usepackage[T1]{fontenc}
  \usepackage[utf8]{inputenc}
  \usepackage{textcomp} % provide euro and other symbols
\else % if luatex or xetex
  \usepackage{unicode-math}
  \defaultfontfeatures{Scale=MatchLowercase}
  \defaultfontfeatures[\rmfamily]{Ligatures=TeX,Scale=1}
\fi
% Use upquote if available, for straight quotes in verbatim environments
\IfFileExists{upquote.sty}{\usepackage{upquote}}{}
\IfFileExists{microtype.sty}{% use microtype if available
  \usepackage[]{microtype}
  \UseMicrotypeSet[protrusion]{basicmath} % disable protrusion for tt fonts
}{}
\makeatletter
\@ifundefined{KOMAClassName}{% if non-KOMA class
  \IfFileExists{parskip.sty}{%
    \usepackage{parskip}
  }{% else
    \setlength{\parindent}{0pt}
    \setlength{\parskip}{6pt plus 2pt minus 1pt}}
}{% if KOMA class
  \KOMAoptions{parskip=half}}
\makeatother
\usepackage{xcolor}
\IfFileExists{xurl.sty}{\usepackage{xurl}}{} % add URL line breaks if available
\IfFileExists{bookmark.sty}{\usepackage{bookmark}}{\usepackage{hyperref}}
\hypersetup{
  pdftitle={{[}Name der Apparatur{]}},
  pdfauthor={Saramaria Schreib},
  hidelinks,
  pdfcreator={LaTeX via pandoc}}
\urlstyle{same} % disable monospaced font for URLs
\usepackage[margin=1in]{geometry}
\usepackage{graphicx,grffile}
\makeatletter
\def\maxwidth{\ifdim\Gin@nat@width>\linewidth\linewidth\else\Gin@nat@width\fi}
\def\maxheight{\ifdim\Gin@nat@height>\textheight\textheight\else\Gin@nat@height\fi}
\makeatother
% Scale images if necessary, so that they will not overflow the page
% margins by default, and it is still possible to overwrite the defaults
% using explicit options in \includegraphics[width, height, ...]{}
\setkeys{Gin}{width=\maxwidth,height=\maxheight,keepaspectratio}
% Set default figure placement to htbp
\makeatletter
\def\fps@figure{htbp}
\makeatother
\setlength{\emergencystretch}{3em} % prevent overfull lines
\providecommand{\tightlist}{%
  \setlength{\itemsep}{0pt}\setlength{\parskip}{0pt}}
\setcounter{secnumdepth}{-\maxdimen} % remove section numbering

\title{{[}Name der Apparatur{]}}
\author{Saramaria Schreib}
\date{January 2021}

\begin{document}
\maketitle

\hypertarget{grundidee}{%
\subsection{Grundidee}\label{grundidee}}

Sachverhalte werden schneller verstanden und langfristig abgespeichert,
wenn das Wissen praktisch angewendet wurde. Genau das ist das Ziel, das
mit diesem Projekt erreicht werden sollte.

Beschrieben wird eine Apparatur, in der Wachstumsprozesse einer
Grünalgen-Batch-Kultur aufgezeichnet und anschließend visualisiert
ausgewertet werden können. Verwendet wurde zur Konstruktion einfache
Messeinrichtung (basierend auf der von Idee von THoams Petzoldt,
siehe:), ein unkomplizierter Aufbau sowie eine leicht zu verstehende und
den Wunschvorstellungen entsprechend anpassbare Software.

Die Apparatur wurde für die Verwendung in schulischen und universitären
Praktika entwickelt. Die Aufzeichnung von Wachstumskurven ist ohne
großen Aufwand möglich. Zudem wird die Bedeutung von Kalibrierungen
deutlich. Der Umgang mit Mikrocontrollern kann erlernt werden.

\hypertarget{die-messapparatur}{%
\section{die Messapparatur}\label{die-messapparatur}}

 \#\# Technik

 gegebenenfalls Tabelle mit
genauer Bezeichnung und Grund der Verwendung - damit spart man sich Text
- wird eher gelesen und ist übersichtlicher

 hier kurz deren Bedeutung
erläutern

 hier ggf
darauf eingehen, dass ja Massenproduktion erfolgen könnte - verdrahtete
Steckbretter hierfür sinnvoll

\hypertarget{software}{%
\subsection{Software}\label{software}}

RSkript hier bitte einfügen und Kurzbeschriebung, was es tut.

\hypertarget{auswertung-der-daten}{%
\section{Auswertung der Daten}\label{auswertung-der-daten}}

\hypertarget{kalibrierung}{%
\subsection{Kalibrierung}\label{kalibrierung}}

\begin{figure}
\centering

\caption{lineare Kalibrierfunktion}
\end{figure}

\hypertarget{wachstumskurven}{%
\subsection{Wachstumskurven}\label{wachstumskurven}}

\begin{figure}
\centering

\caption{Wachstumskurve lr01 (welche hell-dunkel ZEiten?)}
\end{figure}

 \#\# Wachstumsrate

\begin{figure}
\centering

\caption{Wachstumsrate}
\end{figure}

\end{document}

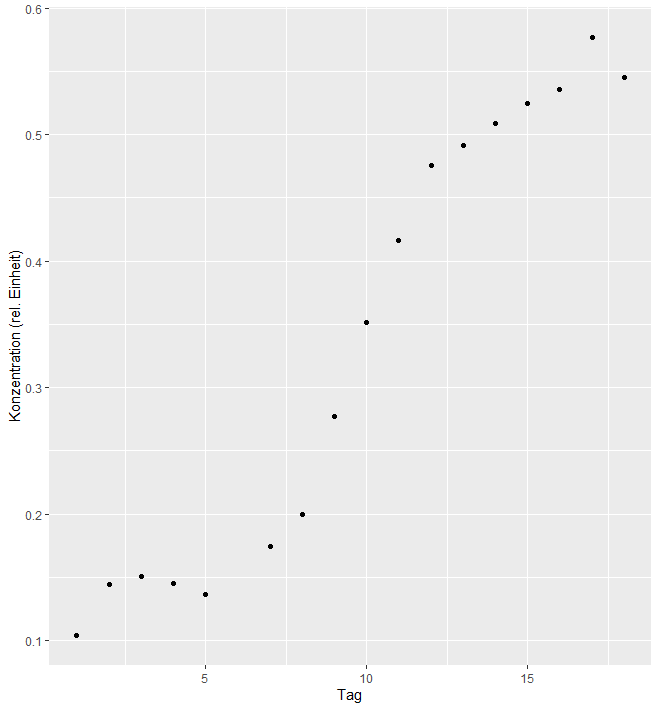
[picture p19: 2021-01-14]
doc/algenlogger/Wachstumskurve_Versuch01_lr02.png

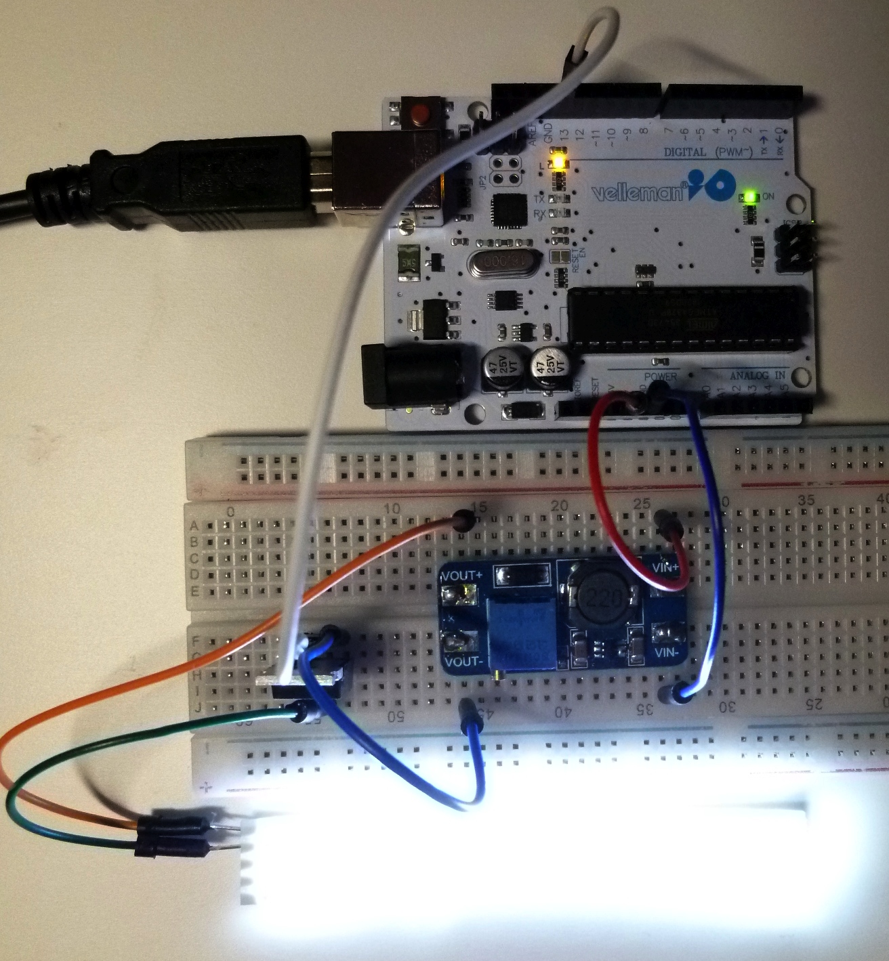
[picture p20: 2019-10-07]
doc/arduino-blink-ledstrip-bright.jpg

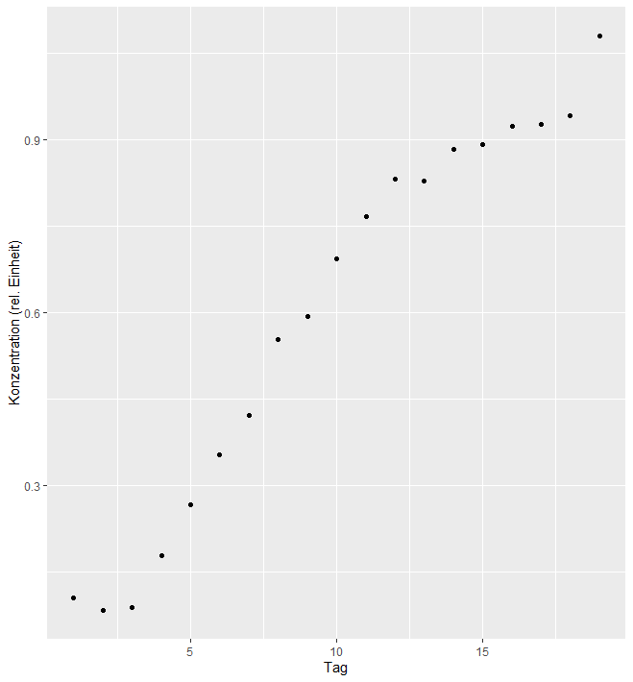
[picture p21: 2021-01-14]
doc/algenlogger/Wachstumskurve_Versuch02_lr03.png

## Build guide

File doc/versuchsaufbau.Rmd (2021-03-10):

---
title: "Versuchsaufbau"
author: "Thomas Petzoldt"
date: "2021-03-10"
output: 
  html_document:
    numbersections: true
    toc: true
    toc_float:
      collapsed: false
      smooth_scroll: true
    code_folding: hide

---

# Grundidee

Die Grundidee besteht im Prinzip aus einer "Lichtschranke", bestehend aus einer LED, 
einem Lichtsensor und einem Messgerät. Das Prinzip ähnelt einem Photometer, allerdings
wird auf Präzisionsoptik und -mechanik verzichtet, um einen kostengünstigen Nachbau
zu ermöglichen.

Im Unterschied zu einem typischen Photometer kann direkt durch das Glas 
der Flasche gemessen werden. Das ist zwar optisch ungünstiger als eine
Küvette, ermöglicht aber Messungen in geschlossenen Kolben oder Flaschen.

Je nach Ausbaustufe kann die Messung manuell erfolgen oder mit einem Mikrocontroller.
Dieser erlaubt gleichzeitig weitere Steuerungsaufgaben, z.B. Licht und Rührer.

Das Experiment ist als Schüler-, Studien- und Praktikumsexperiment vorgesehen. 
Bei entsprechend höherem Aufwand und Kosten für Mechanik, Optik und Elektronik 
ist eine Weiterentwicklung für Forschungszwecke denkbar, allerdings sind
solche Geräte bereits kommerziell erhältlich.

Im Folgenden soll der Versuch, ausgehend von der Grundidee, schrittweise bis zur
Vollautomatisierung und zur Integration in ein Netzwerk (IoT -- Internet of Things)
vorgestellt werden.

Die hier vorliegende Beschreibung stellt den jeweiligen Arbeitsstand dar.

# Phytoplanktonkultur

Für den Versuch wurde eine Laborkultur einer Grünalgenart aus der Gattung *Scenedesmus* verwendet. Diese ist sehr konkurrenzstark und kann unsteril kultiviert werden, was den Versuch sehr erleichtert. Prinzipiell kann man auch eine sogenannte Verdrängungskultur aus einer Freilandprobe ansetzen.

Als Nährlösung wurde ein handelsüblicher mineralischer Blumendünger benutzt. Hier kann man schon einmal das chemische Rechnen üben. Mehr dazu folgt später.

# Experiment 1 

### Manuelle Messung mit Voltmeter

Die einfachste Aufbaustufe zeigt bereits das Grundprinzip. Die Messtrecke wird durch eine
LED und ein Photowiderstand gebildet, die an einem
einfachen Gestell befestigt sind. Das Gestell besteht aus einer Sperrholzgrundplatte, 
Gewindestangen (M4) und etwas Plexiglas, es könnte im Prinzip aber auch aus einem Lego- oder Metallbaukasten stammen.

Als elektronische Bauelemente genügen neben der LED und dem Photowiderstand ein sogenanntes *Breadboard* (Steckbrett), 2 Widerstände, Steckbrücken bzw. etwas Draht und ein Voltmeter. Da nur Spannung gemessen werden muss, genügt ein preiswertes Gerät. Bei der LEDhandelt es sich um eine günstige rote Laser-LED, ähnlich einem Laserpointer. 
Die Laser-LED besitzt sogar eine kleine Linse zur Fokussierung. Grundsätzlich sind auch andere LEDs geeignet. Wichtig ist, dass eine LED immer mit einem Vorwiderstand oder einer Konstantstromquelle (siehe unten) betrieben werden muss, sonst geht sie kaputt. Laser-LEDs sind besonders empfindlich.

**Vorsicht:** Dass man einen Laser nicht auf die Augen oder auf spiegelnde Flächen 
richtet, sollte selbstverständlich sein. Achtung: auch die Flasche kann spiegeln!

Die grüne Farbe der Probe zeigt eine hohe Konzentration gegen Ende eines 
Wachstumsversuchs.

<!--
%![Manuelle Messung mit Voltmeter](led-phot-analog.jpg)
-->

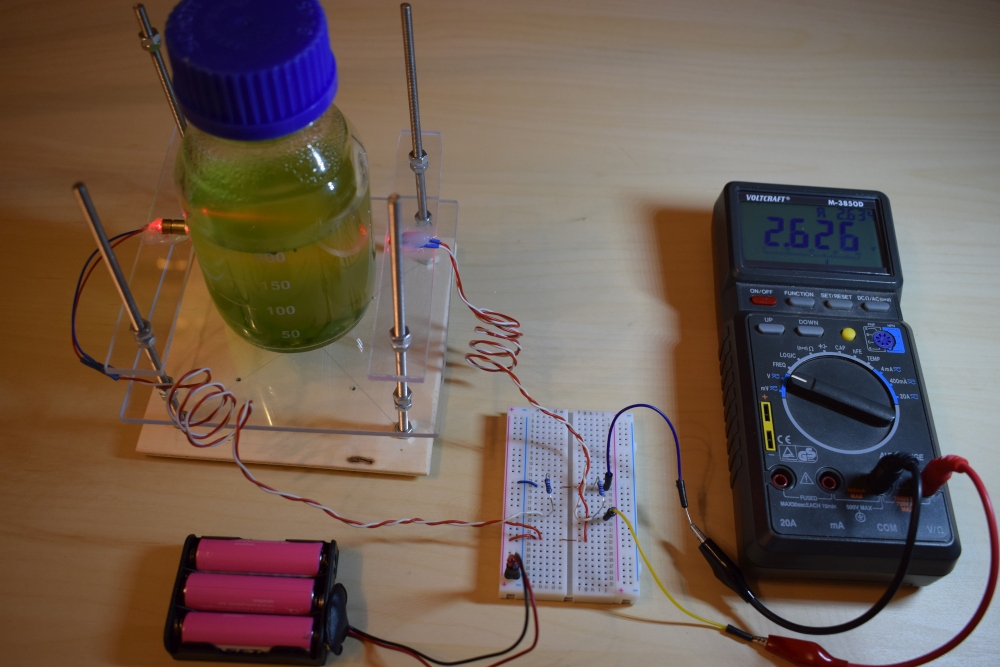
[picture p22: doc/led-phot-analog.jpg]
Manuelle Messung mit Voltmeter

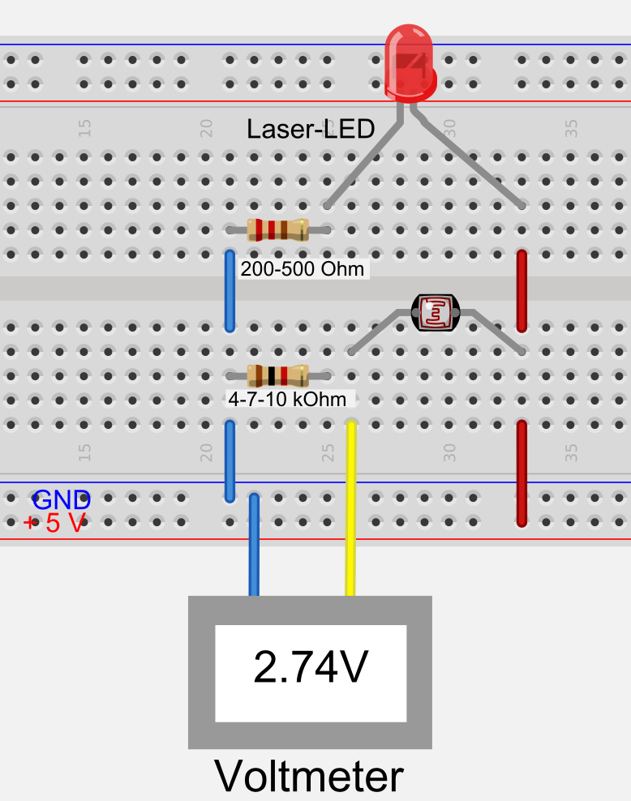
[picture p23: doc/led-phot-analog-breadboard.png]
Schaltung auf dem Breadboard


<!--
![Schaltung](led-phot-analog-breadboard.png)
-->

### Schaltung

Die Schaltung (rechts) zeigt die LED mit Vorwiderstand und für den Photowiderstand 
den typischen Aufbau einer Spannungsteilers. Spannungen lassen sich grundsätzlich 
einfacher und genauer messen als Ströme. Es empfiehlt sich, die Schaltung zunächst 
auf dem Steckbrett aufzubauen. Wenn alles funktioniert, werden LED und Photowiderstand 
mit längeren Leitungen versehen und am Gestell befestigt.

# Experiment 2 

### Messung mit einem Arduino Uno

Der [Arduino Uno](https://www.arduino.cc) und seine kompatiblen Nachbauten (nur Uno genannt) sind in der Mikrocontroller-Bastelszene die "Klassiker". Es gibt zwar inzwischen viel leistungsfähigere Controller: schneller, mehr Speicher, WLAN usw., aber der UNO ist nach wie vor weit verbreitet und besonders einfach zu programmieren.

Im folgenden Experiment wird das Voltmeter durch einen Uno ersetzt, die übrige 
Schaltung bleibt gleich. Die USB-Verbindung mit einem Computer hat eine dreifache Funktion:

- Stromversorgung des Uno (Spannung 5V) 
- Programmierung des Uno mit der [Arduino-IDE](https://www.arduino.cc/en/Main/Software) (IDE = ingegrierte Entwicklungsumgebung)
- Ausgabe der Daten auf dem Bildschirm mittels "Seriellem Monitor" bzw. "Seriellem Plotter" der Arduino-IDE

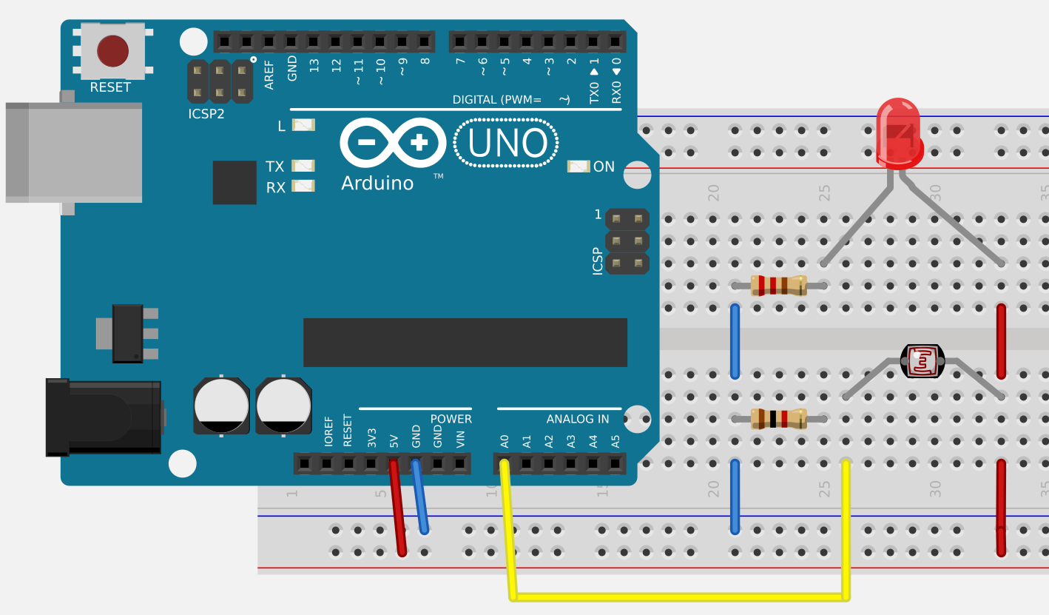
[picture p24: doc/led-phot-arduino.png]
Messung Arduino


### Der Code

Eine Detaillierte Einführung in die Mikrocontrollerprogrammierung würde den Rahmen dieses Projekts übersteigen. Allerdings sind die Installation der Arduino-IDE und erste Gehversuche auf diversen Internetseiten sehr ausführlich beschrieben, z.B. auf https://www.arduino.cc/en/Guide/HomePage

Wenn man die IDE installiert hat und das Blink-Beispiel funktioniert, kann man 
sich bereits and das unten stehende Beispiel trauen. Die Messwerte des Sensors 
erscheinen dann als relative Einheiten auf dem Computer.

```{c eval=FALSE}
/*
  Arduino analog light sensor example
  Output can be shown via the Arduino serial monitor or serial plotter
  License: public domain
*/

int sensorPin = A0;    // pin number where analog input is connected

void setup() {
  Serial.begin(115200);
}

void loop() {
  float sensorValue = analogRead(sensorPin);
  Serial.print("Light: ");
  Serial.println(sensorValue);
  delay(100);
}
```

# Experiment 3

### Arduino mit digitalem Sensor und Display

Für das folgende Experiment benötigen wir einen digitalen Lichtsensor (BH1750) 
und ein OLED-Display (z.B. ein SH1106 mit 128 x 64 Pixeln), beide mit 
sogenannter I2C-Schnittstelle. Der Vorteil on I2C ist, dass man nur 4 Leitungen 
benötigt (Stromversorgung, Masse und 2 Datenleitungen) und dass man mehrere 
Schaltkreise einfach parallel schalten kann.

Prinzipiell sind auch andere Sensoren und Displays geeignet. In diesem Fall sind 
Schaltung und Code entsprechend anzupassen. Vorher sollte man die Chips 
mit den dazugeörigen Beispielen einzeln ausprobieren.

Arduino mit digitalem Sensor und digitalem Display

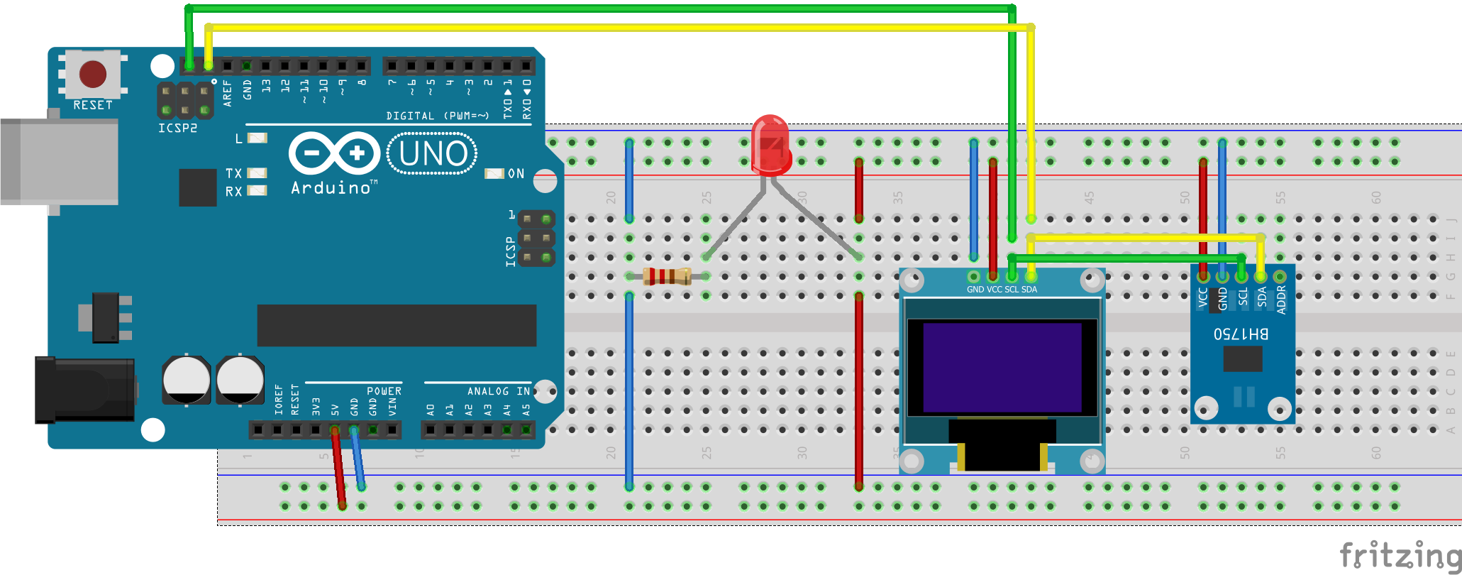
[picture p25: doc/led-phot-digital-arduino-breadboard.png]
Schaltung auf dem Breadboard


Die Abbildungen zeigen oben ein Foto (ohne die Laserdiodenschaltung) 
und unten den kompletten Schaltungsaufbau auf dem Breadboard. Zur Vermeidung von Kabelsalat
wurde der Sensor an ein Flachbandkabel gelötet. Für den Anschluss an den Arduino dienen 
vier Adern eines Dupont-Jumperkabels. Im Foto wurde im Interesse der Übersicht die 
Laserdiodenschaltung weggelassen. Der Versuchsaufbau lässt sich auch als behelfsmäßiges
Luxmeter einsetzen. Man beachte, dass die Stromversorgung über ein Netzteil oder eine Batterie erfolgen kann  (runde Buchse) und nicht über USB, d.h. die Schaltung ist nach der Programmierung autark ohne Computer lauffähig.

### Der Code

```{c eval=FALSE}
/*
  Combines the BH1750 digital Light sensor with an OLED display

  Purpose:
  - simple lux meter 
    (the values are of course not precise, but surprisingly close 
     to a commercial hobby lux meter)
  - in combination with a (laser) LED: digital light sensor for growth experiments

  Connection of light sensor and display to the controller
  The I2C interface allows to connect both in parallel.
  
  Sensor    Arduino Uno
  VCC        3V3
  GND        GND
  SDA        SDA
  SCL        SCL

  Note: available OLED displays have different pinout.
        Be very careful, NEVER CONFUSE 3.3V and GND!

  License: GPL 2.0
*/

//https://github.com/olikraus/u8g2/wiki/u8x8reference
#include <U8x8lib.h>   // OLED display library

// Create the Lightsensor instance
#include <BH1750FVI.h> // light sensor library

// enable one of the following lines to set resolution
BH1750FVI LightSensor(BH1750FVI::k_DevModeContLowRes);
//BH1750FVI LightSensor(BH1750FVI::k_DevModeContHighRes);

// change the following line if you own a different display
U8X8_SH1106_128X64_NONAME_HW_I2C u8x8(/* reset=*/ U8X8_PIN_NONE);

void setup() {
  Serial.begin(9600);
  LightSensor.begin();  

  /* Initialize OLED display */
  u8x8.begin();
  u8x8.setPowerSave(0);
  u8x8.setFont(u8x8_font_7x14_1x2_r);
  u8x8.drawString(0,0,"Start ...");
  delay(100);
  u8x8.clearDisplay();
}

void loop() {
  uint16_t lux = LightSensor.GetLightIntensity();

  // Output to Serial monitor or plotter of the Arduino IDE
  Serial.print("Light: ");
  Serial.println(lux);

  // Output to the OLED display
  u8x8.drawString(0, 2,"Light          "); //overwrite leftover chars from lux
  u8x8.drawString(7, 2, String(lux).c_str());
  delay(1000);
}

```

# Experiment 4

### Internet of Things: Automatische Messeinrichtung mit WLAN

Die oben beschriebene Versuchsanordnung lässt sich beliebig anpassen und erweitern. 
In einer weiteren Ausbaustufe soll der Controller vollautomatisch agieren und die
Messdaten abspeichern. Da der Uno hier schnell an seine Grenzen gelangt, sollte man
einen leistungsfähigen Controller einsetzen, z.B. einen ESP8266 oder einen ESP32.
Entwicklerboards mit diesen Controllern sind kaum teurer als ein Arduino, bieten 
jedoch viel mehr Leistung: kleiner, schneller, mehr Speicher, flexiblere Schnittstellen, 
WLAN, Bluetooth, Stromsparfunktionen.

Für den folgenden Aufbau wurde ein "ESP32 Dev Kit C" verwendet. Er steuert folgende Funktionen:

* Messung der optischen Dichte (mit Photowiderstand)
* Messung der Temperatur mit ein ider mehreren digitalen temperatursensoren (DS18B20)
* An- und ausschalten der Laserdiode
* Steuerung der Beleuchtung (eines LED-Streifens): An/Aus, Helligkeit
* Steuerung eines Magnetrührers
* Zeitsynchronisation von einem Internet-Zeitserver
* WLAN-Übertragung von Messdaten und Steuerinformationen überdas MQTT-Protokoll 
  an einen Datenbankserver.
* Möglichkeit, die Steuerungssoftware im laufenden Betrieb "over the air" 
  (OTA per WLAN) zu aktualisieren. Über diesen Weg lassen sich z.B. das Messintervall
  oder das Rühr- oder Lichtregime (Dauerlicht, 16:8, gepulst) verändern.

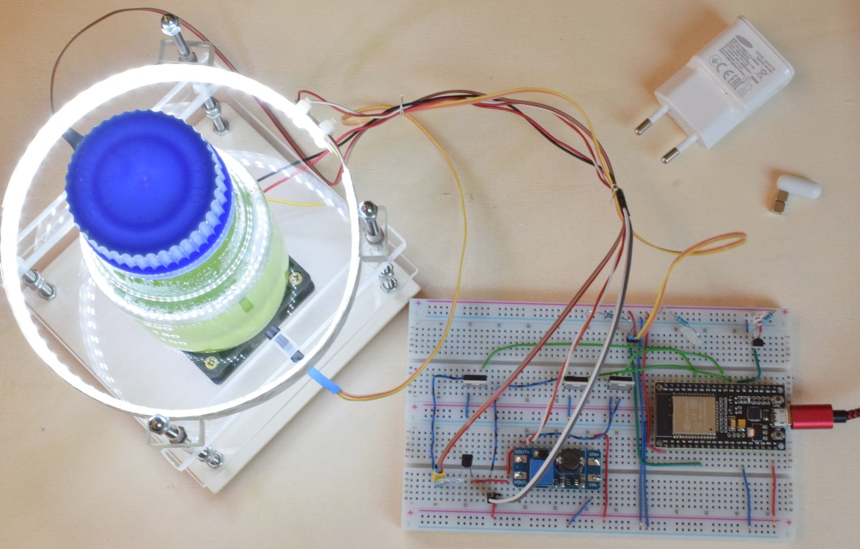
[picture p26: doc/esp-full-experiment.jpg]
Experimenteller Aufbau


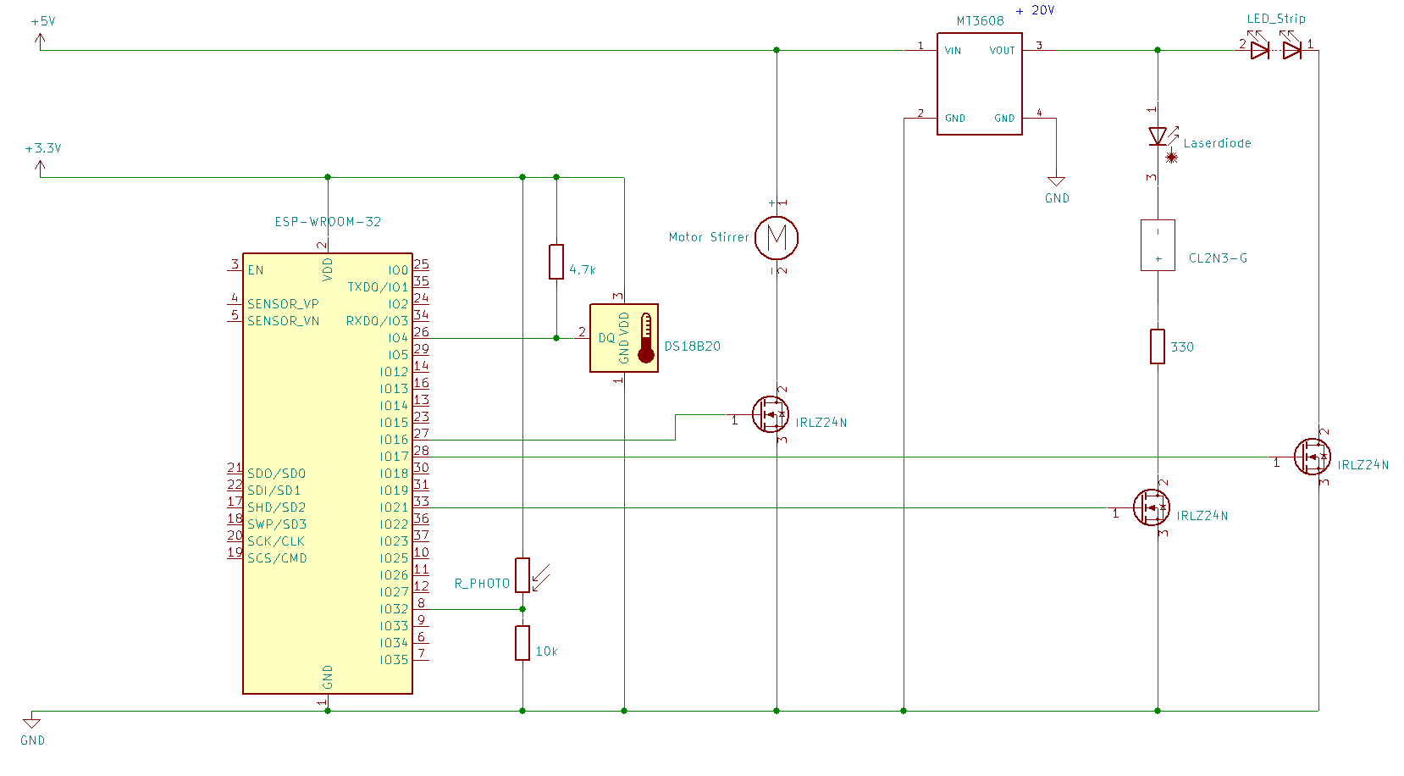
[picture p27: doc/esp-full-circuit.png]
Schaltplan


### Spannungs- und Stromversorgung

Die für den Versuchsaufbau verwendeten Bauelemente benötigen unterschiedliche 
Spannungen (z.B. 3.3V. 5V, 12V, 24V) und Ströme. Während der ESP32 und die Sensoren 
3.3V benötigen (und keinesfalls mehr als 3.6V), benötigt der verwendete Rührermotor 5V
und die LED-Streifen je nach Typ 12V oder 18-24V.

Diese unterschiedlichen Anforderungen wurden wie folgt gelöst.

#### Spannung

* 5V: der ESP32 wird über seinen USB-Eingang mit 5V aus einem Handynetzteil versorgt. 
  Der interne Spannungsregler des "Dev Boards" stellt daraus die 3.3V her.
* 3.3V: Die Sensoren (Photowiderstand, Temperatursensoren) müssen mit dem selben 
Pegel arbeiten wie der ESP. Die dafür benötigte Spannung wird vom 3.3V-Ausgang 
des "Dev Boards" abgezweigt.
* 12V bzw. 24V: Hierzu wird ein kleines aber sehr effizientes Transformatormodul
benutzt (MT3608 DC-DC Step up Modul, auf dem Foto die kleinere Platine). 
Mit Hilfe eines Einstellpotentiometers (blaues Bauteil auf der Platine) 
lässt sich die gewünschte Ausgangsspannung einstellen. Je nach Leistungsfähigkeit der Handy-Netzteils und der maximalen Leistungsaufnahme des LED-Streifens kann die volle Leistung eventuell nicht ganz abgerufen werden, damit für den ESP und die anderen Bauteile genügend Strom übrigbleibt. Im vorliegenden Fall wird der 24V-LED-Streifen nur mit 20V betrieben.

Details sind dem Schaltplan und der folgenden Erläuterung zu entnehmen.

#### Stromstärke

Motoren und LEDs benötigen eventuell mehr Strom (und ggf. eine andere Spannung) 
als der ESP32 von sich aus bereitstellen kann. Prinzipiell kann man das mit Relais lösen.
Als energiesparendere (und billigere) Alternative wurden für diesen Zweck Transistoren verwendet, konkret MOSFETS vom Typ IRLZ24N, oder ein ähnlicher Typ. Sie bieten für den Verwendungszweck genügend Leistungsreserven.

Mit Hilfe der MOSFETs lassen sich die jeweils benötigten Spannungen und Ströme schalten.

#### Temperaturabhängigkeit

Laser-LEDs sind stark temperaturabhängig. Bei einem ersten Versuch kam es trotz 
temperiertem Raum zu relativ starken Schwankungen des Messsignals. Eine vorgeschaltete
Konstantstromquelle (CL2N3-G, 20mA, 0.6W) konnte die Temperaturabhängigkeit sehr stark vermindern.
Das Bauteil hat 2 beschaltete Pins und wird einfach in Reihe zum Laser eingefügt. 
Da am Bauteil jedoch immer ein gewisser Spannungsabfall stattfindet, benötigt 
man nun allerdings eine Spannung von mindestens circa 7 Volt, so dass die Laser-LED
nun über die 12 bzw. 20V-Leitung versorgt werden muss. Ein zusätzlicher Vorwiderstand 
(33o Ohm) sorgt dafür, dass bei 20V die Verlustleistung nicht allein 
an der Konstantstromquelle abfällt.

#### Rührer

Als Rührer kommt ein Selbstbau-Magnetrührer zum Einsatz, bestehend aus 
einem kleinen PC-Lüfter mit aufgeklebten Neodym-Magnetwürfeln. Da Motoren selbst 
Magnete besitzen, funktioniert das nur bei bestimmten Typen (vorher ausprobieren).

Im Versuchsgefäß befindet sich ein handelsüblicher Labor-Magnetrührer 
(sogenannter [Rührfisch](https://de.wikipedia.org/wiki/Magnetr%C3%BChrer)) 
oder ein Selbstbau aus Schrumpfschlauch, Magnetwürfeln und Kleber.

Alternativ kann man auch einen Rührer von oben bauen, z.B. aus einem kleinen Motor und dem Stempel einer Einwegspritze, oder eine Belüftung mit Hilfe einer Niederspannungs-Aquarienpumpe.

# Schüler- und Studienprojekte

## Organismen und Nährmedien

* Planktonkultur: Untersuchung unterschiedlicher Algenarten
* Nährmedien: In welchem Nährmedium wachsen die Algen am besten
* Lichtregime: Wachstum bei Dauerlicht und im Tag-Nacht-Rhythmus
* Verbesserung von Mechanik, Optik und Elektronik
* Verbesserung der Software

## Datenanalyse und Statistik

* Datenmanagement
* Kalibrierung
* Plotten, Zeitreihen, Glättung
* ANOVA-Beispiel
* Webseite zum Nachmachen

## Zusätzliche Programme und Scripte

* MQTT-Server auf einem Raspberry Pi
* Python-Server-Script und MariaDB-Datenbank
* Visualisierung mit R und Shiny

----

**Copyright and original author:** [tpetzoldt](https://github.com/tpetzoldt), `r Sys.Date()`

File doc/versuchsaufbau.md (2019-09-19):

---
title: "Versuchsaufbau"
author: "Thomas Petzoldt"
date: "2019-09-17"
output: 
  html_document:
    numbersections: true
    toc: true
    toc_float:
      collapsed: false
      smooth_scroll: true
    code_folding: show

---

# Grundidee

Die Grundidee besteht praktisch in einer "Lichtschranke", bestehend aus einer LED 
einem Lichtsensor und einem Messgerät. Das Prinzip ähnelt einem Photometer, allerdings
wird auf Präzisionsoptik und -mechanik verzichtet, um einen kostengünstigen Nachbau
zu ermöglichen.

Im Unterschied zu einem typischen Photometer kann direkt durch das Glas 
der Flasche gemessen werden. Das ist zwar optisch ungünstiger als eine
Küvette, ermöglicht aber Messungen in geschlossenen Kolben oder Flaschen.

Je nach Ausbaustufe kann die Messung manuell erfolgen oder mit einem Mikrocontroller.
Dieser erlaubt dann auch weitere Steuerungsaufgaben, z.B. Licht und Rührer.

Das Experiment ist als Schüler-, Studien- und Praktikumsexperiment vorgesehen. 
Bei entsprechend höherem Aufwand und Kosten für Mechanik, Optik und Elektronik 
ist eine Weiterentwicklung für Forschungszwecke denkbar, allerdings sind
solche Geräte bereits kommerziell erhältlich.

Im folgenden soll der Versuch, ausgehend von der Grundidee, schrittweise bis zur
Vollautomatisierung und zur Integration in ein Netzwerk (IoT -- Internet of Things)
vorgestellt werden.

Das hier vorgefundene Dokument stellt den jeweiligen Arbeitsstand dar.

# Phytoplanktonkultur

Im vorliegenden Fall wird eine Kultur der Grünalge *Scenedesmus* verwendet. Diese 
Art ist sehr konkurrenzstark und kann unsteril kultiviert werden, was den Versuch sehr 
erleichtert. Prinzipiell kann man auch eine sogenannte Verdrängungskultur aus einer
Freilandprobe ansetzen.

Als Nährlösung wird ein handelsüblicher mineralischer Blumendünger 
benutzt. Hier kann man schon einmal das chemische Rechnen üben. Mehr dazu folgt später.

# Experiment 1: Manuelle Messung mit einem Voltmeter

Die einfachste Aufbaustufe zeigt bereits das Grundprinzip. Die Messtrecke wird durch eine
LED und ein Photowiderstand gebildet, die an einem
Gestell befestigt sind. Das Gestell besteht im vorliegenden Fall aus einer Sperrholzgrundplatte, 
Gewindestangen (M4) und etwas Plexiglas, könnte im Prinzip aber auch aus dem Lego- oder Metallbaukasten stammen.

Als elektronische Bauelemente genügen neben der LED und dem Photowiderstand ein sogenanntes *Breadboard* (Steckbrett),
2 Widerstände, Steckbrücken bzw. etwas Draht und ein Voltmeter. Da nur Spannung gemessen werden muss, genügt ein preiswertes Gerät. Zur LED ist zu sagen, dass es sich hier um eine günstige Laser-LED (ähnlich einem Laserpointer) handelt. 
Diese besitzt sogar eine kleine Linse zur Fokussierung. Grundsätzlich sind auch andere LEDs geeignet. Wichtig ist, dass
eine LED fast immer mit einem Vorwiderstand oder einer Konstantstromquelle (siehe unten) betrieben werden muss, sonst geht sie kaputt. Laser-LEDs sind besonders empfindlich.

**Vorsicht:** Das man einen Laser nicht auf die Augen oder auf spiegelnde Flächen 
richtet, sollte selbstverständlich sein. Achtung: auch die Flasche kann spiegeln!

Die grüne Farbe der Probe zeigt eine hohe Konzentration gegen Ende eines 
Wachstumsversuchs.

<!--
%![Manuelle Messung mit Voltmeter](led-phot-analog.jpg)
-->

Manuelle Messung mit Voltmeter
Schaltung auf dem Breadboard

<!--
![Schaltung](led-phot-analog-breadboard.png)
-->

Die Schaltung (rechts) zeigt für die LED den Vorwiderstand und für den Photowiderstand 
den typischen Aufbau einer Spannungsteilers. Spannungen lassen sich grundsätzlich 
einfacher und genauer messen als Ströme. Es empfiehlt sich, die Schaltung zunächst 
auf dem Steckbrett aufzubauen. Wenn alles funktioniert, werden LED und Photowiderstand 
mit längeren Leitungen versehen und am Gestell befestigt.

# Experiment 2: Messung mit einem Arduino Uno

Der [Arduino Uno](https://www.arduino.cc) und seine kompatiblen Nachbauten (nur Uno genannt) sind in der Mikrocontroller-Bastelszene
praktisch die "Klassiker". Es gibt inzwischen zwar viel leistungsfähigere Controller: schneller, mehr Speicher, WLAN usw., aber der UNO ist nach wie vor weit verbreitet und besonders einfach zu programmieren.

Im folgenden Experiment wird das Voltmeter durch einen Uno ersetzt, die übrige 
Schaltung bleibt gleich. Die USB-Verbindung mit einem Computer hat eine dreifache Funktion:

- Stromversorgung des Uno (Spannung 5V) 
- Programmierung des Uno mit der [Arduino-IDE](https://www.arduino.cc/en/Main/Software) (IDE = ingegrierte Entwicklungsumgebung)
- Ausgabe der Daten auf dem Bildschirm mittels "Seriellem Monitor" bzw. "Seriellem Plotter" der Arduino-IDE

Messung Arduino

### Der Code

Eine Detaillierte Einführung in die Mikrocontrollerprogrammierung würde den Rahmen dieses Projekts
sprengen. Die Installation Arduino-IDE sowie erste Gehversuche sind auf diversen Internetseiten sehr ausführlich beschrieben, z.B. auf https://www.arduino.cc/en/Guide/HomePage

Wenn man die IDE installiert hat und das Blink-Beispiel funktioniert, kann man 
sich bereits and das unten stehende Beispiel trauen. Die Messwerte des Sensors 
erscheinen dann als relative Einheiten auf dem Computer.

```{C++}
/*
  Arduino analog light sensor example
  Output can be shown via the Arduino serial monitor or serial plotter
  License: public domain
*/

int sensorPin = A0;    // pin number where analog input is connected

void setup() {
  Serial.begin(115200);
}

void loop() {
  float sensorValue = analogRead(sensorPin);
  Serial.print("Light: ");
  Serial.println(sensorValue);
  delay(100);
}
```

# Experiment 3: Arduino mit digitalem Lichtsensor und eigenem Display

Für das folgende Experiment benötigen wir einen digitalen Lichtsensor (BH1750) 
und ein OLED-Display (z.B. ein SH1106 mit 128 x 64 Pixeln), beide mit 
sogenannter I2C-Schnittstelle. Der Vorteil on I2C ist, dass man nur 4 Leitungen 
benötigt (Stromversorgung, Masse und 2 Datenleitungen) und dass mehrere beide Schaltkreise 
einfach parallel schalten kann.

Prinzipiell sind auch andere Sensoren und Displays geeignet. In diesem Fall sind 
Schaltung und Code entsprechend anzupassen. Vorher sollte man die Chips 
mit den dazugeörigen Beispielen einzeln ausprobieren.

Arduino mit digitalem Sensor und digitalem Display

Schaltung auf dem Breadboard

Die Abbildungen zeigen oben ein Foto (ohne die Laserdiodenschaltung) 
und unten den kompletten Schaltungsaufbau auf dem Breadboard. Zur Vermeidung von Kabelsalat
wurde der Sensor an ein Flachbandkabel gelötet. Für den Anschluss an den Arduino dienen vier 
Adern eines Dupont-Jumperkabels. Im Foto wurde im Interesse der Übersicht die 
Laserdiodenschaltung weggelassen. Der Versuchsaufbau lässt sich auch als behelfsmäßiges
Luxmeter einsetzen. Man beachte, dass die Stromversorgung über ein Netzteil erfolgen kann 
(runde Buchse) und nicht über USB, d.h. die Schaltung ist nach der Programmierung
autark ohne Computer lauffähig.

```{C++}
/*
  Combines the BH1750 digital Light sensor with an OLED display

  Purpose:
  - simple lux meter 
    (the values are of course not precise, but surprisingly close 
     to a commercial hobby lux meter)
  - in combination with a (laser) LED: digital light sensor for growth experiments

  Connection of light sensor and display to the controller
  The I2C interface allows to connect both in parallel.
  
  Sensor    Arduino Uno
  VCC        3V3
  GND        GND
  SDA        SDA
  SCL        SCL

  Note: available OLED displays have different pinout.
        Be very careful, NEVER CONFUSE 3.3V and GND!

  License: GPL 2.0
*/

//https://github.com/olikraus/u8g2/wiki/u8x8reference
#include <U8x8lib.h>   // OLED display library

// Create the Lightsensor instance
#include <BH1750FVI.h> // light sensor library

// enable one of the following lines to set resolution
BH1750FVI LightSensor(BH1750FVI::k_DevModeContLowRes);
//BH1750FVI LightSensor(BH1750FVI::k_DevModeContHighRes);

// change the following line if you own a different display
U8X8_SH1106_128X64_NONAME_HW_I2C u8x8(/* reset=*/ U8X8_PIN_NONE);

void setup() {
  Serial.begin(9600);
  LightSensor.begin();  

  /* Initialize OLED display */
  u8x8.begin();
  u8x8.setPowerSave(0);
  u8x8.setFont(u8x8_font_7x14_1x2_r);
  u8x8.drawString(0,0,"Start ...");
  delay(100);
  u8x8.clearDisplay();
}

void loop() {
  uint16_t lux = LightSensor.GetLightIntensity();

  // Output to Serial monitor or plotter of the Arduino IDE
  Serial.print("Light: ");
  Serial.println(lux);

  // Output to the OLED display
  u8x8.drawString(0, 2,"Light          "); //overwrite leftover chars from lux
  u8x8.drawString(7, 2, String(lux).c_str());
  delay(1000);
}

```

# Ausblick: Internet of Things: Automatische Messeinrichtung mit WLAN

Die oben beschriebene Versuchsanordnung lässt sich beliebig anpassen und erweitern. 
In einer weiteren Ausbaustufe soll der Controller vollautomatisch agieren und die
Messdaten abspeichern. Da der Uno hier schnell an seine Grenzen gelangt, sollte man
einen leistungsfähigen Controller einsetzen, z.B. einen ESP8266 oder einen ESP32.
Entwicklerboards mit diesen Controllern sind kaum teurer als ein Arduino, bieten 
jedoch viel mehr Leistung: kleiner, schneller, mehr Speicher, flexiblere Schnittstellen, 
WLAN, Bluetooth, Stromsparfunktionen.

Für den folgenden Aufbau wurde ein "ESP32 Dev Kit C" verwendet. Er steuert folgende Funktionen:

* Messung der optischen Dichte (mit Photowiderstand)
* Messung der Temperatur mit ein ider mehreren digitalen temperatursensoren (DS18B20)
* An- und ausschalten der Laserdiode
* Steuerung der Beleuchtung (eines LED-Streifens): An/Aus, Helligkeit
* Steuerung eines Magnetrührers
* Zeitsynchronisation von einem Internet-Zeitserver
* WLAN-Übertragung von Messdaten und Steuerinformationen überdas MQTT-Protokoll 
  an einen Datenbankserver.
* Möglichkeit, die Steuerungssoftware im laufenden Betrieb "over the air" 
  (OTA per WLAN) zu aktualisieren. Über diesen Weg lassen sich z.B. das Messintervall
  oder das Rühr- oder Lichtregime (Dauerlicht, 16:8, gepulst) verändern.

Experimenteller Aufbau

Schaltplan

### Spannungs- und Stromversorgung

Die für den Versuchsaufbau verwendeten Bauelemente benötigen unterschiedliche 
Spannungen (z.B. 3.3V. 5V, 12V, 24V) und Ströme. Während der ESP32 und die Sensoren 
3.3V benötigen (und keinesfalls mehr als 3.6V), benötigt der verwendete Rührermotor 5V
und die LED-Streifen je nach Typ 12V oder 18-24V.

Diese unterschiedlichen Anforderungen wurden wie folgt gelöst.

#### Spannung

* 5V: der ESP32 wird über seinen USB-Eingang mit 5V aus einem Handynetzteil versorgt. 
  Der interne Spannungsregler des "Dev Boards" stellt daraus die 3.3V her.
* 3.3V: Die Sensoren (Photowiderstand, temperatursensoren) müssen mit dem selben 
Pegel arbeiten wie der ESP. Die dafür benötigte Spannung wird vom 3.3V-Ausgang 
des "Dev Boards" abgezweigt.
* 12V bzw. 24V: Hierzu wird ein kleines aber sehr effizientes Transformatormodul
benutzt (MT3608 DC-DC Step up Modul, auf dem Foto die kleinere Platine). 
Mit Hilfe eines Einstellpotentiometers (blaues bauteil auf der Platine) 
lässt sich die gewünschte Ausgangsspannung einstellen. Je nach Leistungsfähigkeit der Handy-Netzteils und der maximalen Leistungsaufnahme des LED-Streifens kann die volle Leistung eventuell nicht ganz abgerufen werden, damit für den ESP und die anderen bauteile genügend Strom übrigbleibt. Im vorliegenden Fall wird der 24V-LED-Streifen nur mit 20V betrieben.

Details sind dem Schaltplan und der folgenden Erläuterung zu entnehmen.

#### Strom

Motoren und LEDs benötigen eventuell mehr Strom (und ggf. eine andere Spannung) 
als der ESP32 von sich aus bereitstellen kann. Prinzipiell kann man das mit Relais lösen.
Als energiesparendere (und billigere) Alternative wurden für diesen Zweck Transistoren verwendet,
konkret MOSFETS vom Typ IRLZ24N. Sie bieten für den verwendungszweck genügend Leistungsreserven.

Mit Hilfe der MOSFETs lassen sich die jeweils benötigten Spannungen schalten.

#### Temperaturabhängigkeit

Laser-LEDs sind stark temperaturabhängig. Bei einem ersten Versuch kam es trotz 
temperiertem Raum zu relativ starken Schwankungen des Messignals. Eine vorgeschaltete
Konstantstromquelle (CL2N3-G, 20mA, 0.6W) konnte die Temperaturabhängigkeit sehr stark vermindern.
Das Bauteil hat 2 beschaltete Pins und wird einfach in Reihe zum Laser eingefügt. 
Da am Bauteil jedoch immer ein gewisser Spannungsabfall stattfindet, benötigt 
man nun allerdings eine Spannung von mindestens circa 7 Volt, so dass die Laser-LED
nun über die 12 bzw. 20V-Leitung versorgt werden muss. Ein zusätzlicher Vorwiderstand 
(33o Ohm) sorgt dafür, dass bei 20V die Verlustleistung nicht allein 
an der Konstantstromquelle abfällt.

#### Rührer

Als Rührer kommt ein Selbstbau-Magnetrührer zum Einsatz, bestehend aus 
einem kleinen PC-Lüfter mit aufgeklebten Neodym-Magnetwürfeln. Da Motoren selbst 
Magnete besitzen, funktioniert das nur bei bestimmten Typen (vorher ausprobieren).

Im Versuchsgefäß befindet sich ein handelsüblicher Labor-Magnetrührer 
(sogenannter [Rührfisch](https://de.wikipedia.org/wiki/Magnetr%C3%BChrer)) 
oder ein Selbstbau aus Schrumpfschlauch, Magnetwürfeln und Kleber.

# Folgt demnächst ...

## Biologie

* Planktonkultur
* Nährmedien
* Versuche und Ideen

## Programmierung

* Arduino / ESP
* Raspberry Pi
* Python-Server-Script und MariaDB-Datenbank
* Visualisierung mit R und Shiny

## Datenanalyse und Statistik

* Datenmanagement
* Plotten, Zeitreihen, Glättung
* ANOVA-Beispiel

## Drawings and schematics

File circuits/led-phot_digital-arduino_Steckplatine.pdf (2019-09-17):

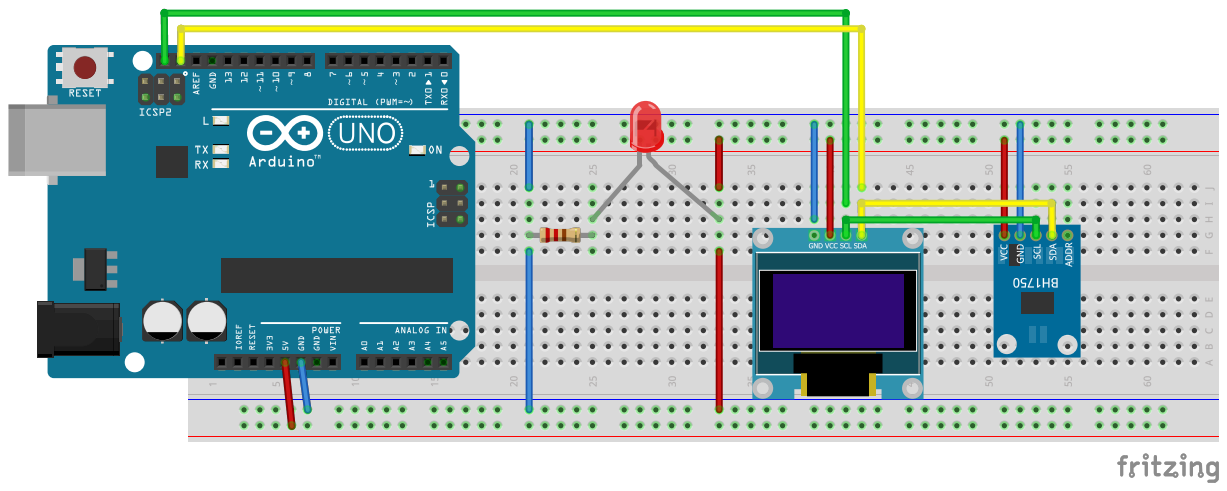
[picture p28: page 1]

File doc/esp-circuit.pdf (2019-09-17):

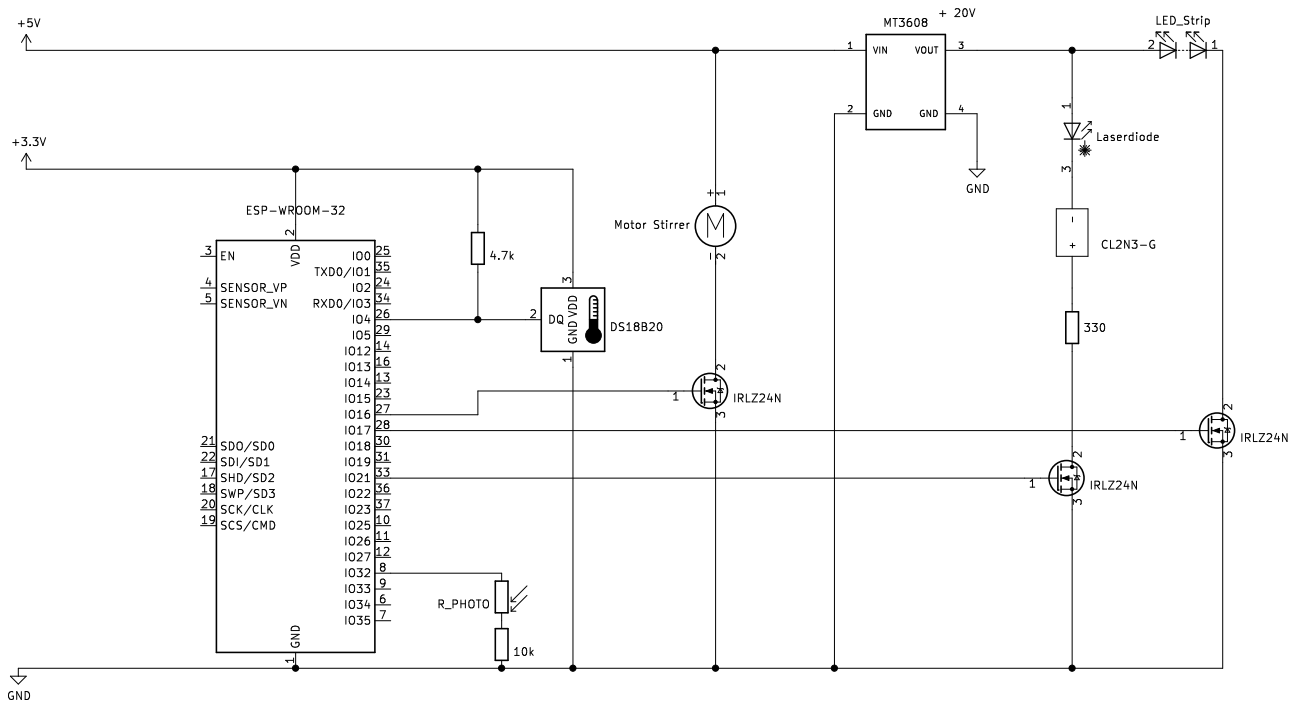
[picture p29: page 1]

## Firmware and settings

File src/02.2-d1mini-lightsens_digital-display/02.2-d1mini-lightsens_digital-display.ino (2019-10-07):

/*
  Combines the BH1750 digital Light sensor with an OLED display

  Purpose:
  - simple lux meter 
    (the values are of course not precise, but surprisingly close 
     to a commercial hobby lux meter)
  - in combination with a (laser) LED: digital light sensor for growth experiments
  - optional sensors: 
    - analog light sensor (photoresistor)
    - digital temperature sensor (DS18B20)
  
  
  Controller  : Arduino Uno (works also with ESP8266 boards)
  Light sensor: BH1750
  Display     : SH1106  (1.3" I2C)

  Connection of light sensor and display to the controller
  The I2C interface allows to connect both in parallel.
  
  Sensor    Arduino Uno    NodeMCU ESP8266:
  VCC        3V3            3V3
  GND        GND            GND
  SDA        A4/SDA         D2
  SCL        A5/SCL         D1

  Note: available OLED displays have different pinout.
        Be very careful, NEVER CONFUSE 3.3V and GND!


  Created from online examples by https://github.com/tpetzoldt
  License: GPL 2.0
*/

// ----- OLED display ----------------------------------------
//https://github.com/olikraus/u8g2/wiki/u8x8reference
#include <U8x8lib.h>   // OLED display library

// change the following line if you own a different display
U8X8_SH1106_128X64_NONAME_HW_I2C u8x8(/* reset=*/ U8X8_PIN_NONE);


// ----- BH 1750 light sensor  --------------------------------
// Create the Lightsensor instance 
#include <BH1750FVI.h> // light sensor library

// ----- analog light sensor ----------------------------------
#define analog A0

// enable one of the following lines to set resolution
BH1750FVI LightSensor(BH1750FVI::k_DevModeContLowRes);
//BH1750FVI LightSensor(BH1750FVI::k_DevModeContHighRes);

// ----- DS18B20 temperature sensor  -------------------------
#include <OneWire.h>
#include <DallasTemperature.h>
#define ONE_WIRE_BUS 2 // 2=GPIO4 D1 mini
OneWire oneWire(ONE_WIRE_BUS);
DallasTemperature sensors(&oneWire);

// ----- LEDs ------------------------------------------------
#define red 12   // 6
#define white 13 // 7

void setup() {
  Serial.begin(9600);
  LightSensor.begin();  

  sensors.begin();
  sensors.setResolution(12); // 12 bit

  /* Initialize OLED display */
  u8x8.begin();
  u8x8.setPowerSave(0);
  u8x8.setFont(u8x8_font_7x14_1x2_r);
  u8x8.drawString(0,0,"Start ...");
  delay(100);
  u8x8.clearDisplay();

  pinMode(red, OUTPUT);
  pinMode(white, OUTPUT);
}

int i=10;

void loop() {

  if (i < 2) {
    digitalWrite(red, HIGH);
    digitalWrite(white, LOW);
    u8x8.drawString(14, 5, "*");
  } else {
    digitalWrite(red, LOW);
    digitalWrite(white, HIGH);
  }
  
  uint16_t lux = LightSensor.GetLightIntensity();

  sensors.setWaitForConversion(false);
  sensors.requestTemperatures();

  double temp = sensors.getTempCByIndex(0);
  double turb = 100.0 - 100.0*float(analogRead(analog)/1024.0);
  Serial.print("Temp: ");
  Serial.print(temp);
  Serial.print("\tLux: ");
  Serial.print(lux);
  Serial.print("\tOD: ");
  Serial.println(turb);
  
  // Output to the OLED display
  //u8x8.clearDisplay();
  //u8x8.clearLine(0, 2); // announced for future versions v2.14 of the u8x8 lib
  u8x8.drawString(0, 1,"Temp            "); //overwrite leftover chars
  u8x8.drawString(7, 1, String(temp).c_str());
  
  u8x8.drawString(0, 3,"Lux             "); //overwrite leftover chars
  u8x8.drawString(7, 3, String(lux).c_str());

  u8x8.drawString(0, 5,"OD              "); //overwrite leftover chars
  u8x8.drawString(7, 5, String(turb).c_str());

  i++;
  if (i > 14) i = 0;
  delay(1000);
}

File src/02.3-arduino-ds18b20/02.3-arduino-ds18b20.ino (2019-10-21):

// Arduino IDE Script from:
// https://create.arduino.cc/projecthub/TheGadgetBoy/ds18b20-digital-temperature-sensor-and-arduino-9cc806
//
// modified by ThPe
//
// Data visualization from Arduino IDE or with R script
//


/********************************************************************/
// First we include the libraries
#include <OneWire.h> 
#include <DallasTemperature.h>

/********************************************************************/
// Data wire is plugged into pin 2 on the Arduino 
#define ONE_WIRE_BUS 2 

/********************************************************************/
// Setup a oneWire instance to communicate with any OneWire devices  
// (not just Maxim/Dallas temperature ICs) 
OneWire oneWire(ONE_WIRE_BUS); 

/********************************************************************/
// Pass our oneWire reference to Dallas Temperature. 
DallasTemperature sensors(&oneWire);

/********************************************************************/ 
void setup(void) { 
 // start serial port 
 Serial.begin(9600); 
 Serial.println("Dallas Temperature IC Control Library Demo"); 
 // Start up the library 
 sensors.begin(); 
} 

void loop(void) { 
 // call sensors.requestTemperatures() to issue a global temperature 
 // request to all devices on the bus 
/********************************************************************/
 Serial.print(" Requesting temperatures..."); 
 sensors.requestTemperatures(); // Send the command to get temperature readings 
 Serial.println("DONE"); 
/********************************************************************/
 Serial.print("Temperature is: "); 
 Serial.print(sensors.getTempCByIndex(0)); // Why "byIndex"?  
   // You can have more than one DS18B20 on the same bus.  
   // 0 refers to the first IC on the wire 
   delay(1000); 
} 

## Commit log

2019-09-17 initial source code and doc
    [led-phot-arduino.fzz, led-phot-simple.fzz, led-phot_digital+analog-arduino.fzz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]
2019-09-19 fix brackets
2019-10-07 blink example source code
    [led-blink.fzz]
2019-10-14 blink with 2 LEDs
2021-01-14 reduce memory footprint
2021-01-23 add Frititzing file "algenlogger" from Sara
    [algenlogger_hauptsteckbrett.fzz]
2021-03-10 corrected circuit
